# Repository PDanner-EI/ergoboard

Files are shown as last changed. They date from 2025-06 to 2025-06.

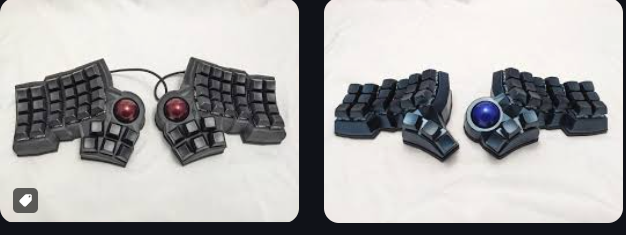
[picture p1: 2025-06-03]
obsidian/Keyboards/_images/kb_cosmos.png

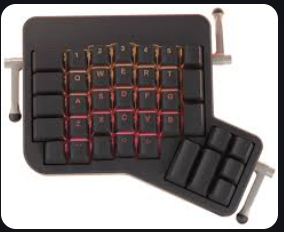
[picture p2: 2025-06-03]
obsidian/Keyboards/_images/kb_zsa_ergodox_ez.png

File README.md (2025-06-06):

# ergoboard
Repo to document all my progress and files on the journey of finding the most comfortable and efficient keyboard.

## Directories:
- See [3d_files](https://github.com/PDanner-EI/ergoboard/tree/main/3d_files) for all used 3d-files
- See [kle](https://github.com/PDanner-EI/ergoboard/tree/main/kle) for the visual layout .json of the keyboard, using Keyboard Layout Manager
- See [obsidian](https://github.com/PDanner-EI/ergoboard/tree/main/obsidian) for all documentations
- See [qmk_firmware](https://github.com/PDanner-EI/ergoboard/tree/main/qmk_firmware/cosmotyl) for the current firmware copied out of the QMK keyboard directory

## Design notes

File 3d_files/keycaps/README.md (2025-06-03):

Source: https://www.printables.com/model/865075-des-keycaps-for-keyboard-cherry-mx-version

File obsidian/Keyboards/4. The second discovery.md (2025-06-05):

# Cosmos keyboards
![[kb_cosmos.png]]
[Online tool](https://ryanis.cool/cosmos/beta)
+++fully customizable everything
+++solves all problems
++open source

ergonomic bonus:
+++fully ergonomic

bonus:
+encoders/trackballs/displays/joysticks
+wide range of controllers

---
[[5. The Cosmos keyboard V1|Next > The Cosmos keyboard V1]]

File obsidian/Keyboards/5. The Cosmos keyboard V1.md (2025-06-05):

Example:![[kb_cosmos_model.png]]

# Custom model V1
![[kb_cosmos_model_V1.png]]
[V1](https://ryanis.cool/cosmos/beta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)
+physical layout fully adjusted to my hands and fingers
+minimal layout 3x6 + 3 thumbs
+added trackball for faster scrolling and clicking
+added encoder (current application in testing)
+++solves all problems

ergonomic bonus:
+split
+angled keys
+thumb keys + angled

# Assembly guides
==!!!Definitely use thin magnet wire/Kupferlackdraht!!!==
https://ryanis.cool/cosmos/docs/qmk-rp2040/
https://ryanis.cool/cosmos/plum-twist/wiring

# Firmware
[QMK](https://docs.qmk.fm)

# Components
## Socket PCBs
* [Plum twist](https://github.com/rianadon/Cosmos-Keyboard-PCBs/tree/main/plum-twist)
	Individual small PCBs that rotate into place
	--super annoying and tedious to solder and wire
	++switch layout doesn't matter; can shape to any curvature
	+able to swap out the entire electronics without disassembly

## Keycaps
- 42+: 1u DES Keycaps
	- [x] print [DES keycaps(printables)(~0€)](https://www.printables.com/model/865075-des-keycaps-for-keyboard-cherry-mx-version)

## Switches
- 42+: MX-Compatible Switches
	- [x] test [Cherry MX experience box(amazon)(9,99€)](https://www.amazon.de/CHERRY-Tastatur-Schalter-Gaming-Keyboard-Ausprobieren-Kennenlernen/dp/B0CC2WZLQ3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)
	- [x] or [Cherry MX experience box(shop.cherry)(9,99€)](https://shop.cherry.de/de-de/mx-experience-box.html)
	- [x] [cherry silent red(amazon)(34,99)](https://www.amazon.de/dp/B09ZTGPPN6)
	- [x] [Gazzew Boba U4(splitkb)(33,58)](https://splitkb.com/products/gazzew-boba-u4-silent-tactile-switch?variant=43579262566659)

## Trackball
- 3: 3 x 6 x 2.5mm Bearings {option 1} (HARD TO TURN)
	- [ ] [4 Stueck MR63ZZ(ebay)(6,10€)](https://www.ebay.de/itm/376084342403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)
- 3: 3 x 8mm Dowel Pins {option 1} (HARD TO TURN)
	- [ ] [5 Zylinderstifte 3x8mm(ebay)(4,10)](https://www.ebay.de/itm/312197203836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)
- 3: BTU 7.5mm {option 2} (NOISY!!!)
	- [x] [Ball Transfer Unit 7.5 QB311(aliexpress)(2,85)](https://www.aliexpress.us/item/1005005411108700.html?gatewayAdapt=4itemAdapt)
- 3: Ball Bearings {option 3} (SILENT)
	- [x] salvaged from old drawer slide
- 1: PMW3360 or PMW3389 Sensor
	- [x] [PMW3389DM-T3QU(aliexpress)(8,09)](https://de.aliexpress.com/item/1005007468783392.html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)
- PMW3389 breakout [PCBs](https://github.com/Zorahmella/Ogen)
	- [x] Self-Ordered via JLCPCB
- 1: 34mm Trackball
	- [x] [Perixx Peripro-303 Ersatztrackball(amazon)(12,03)](https://www.amazon.de/Perixx-PERIPRO-303GB-Trackball-Ersatzball-Kensington/dp/B07BDF725X?th=1)
	- [ ] [Perixx Peripro-303 Ersatztrackball(perixx)(11,99)](https://de.perixx.com/products/peripro-303_glossy?variant=48187580449033)

## Encoders
- 2: EC11
	- [x] [5 EC11(aliexpress)(1,39)](https://de.aliexpress.com/item/1005005983134515.html)
- 67+: 1N148 Diodes
	- [x] [1N4180(reichelt)(1,90)](https://www.reichelt.de/de/de/shop/produkt/schalt-diode_100_v_150_ma_do-35-1730)

## Mounting
- 18: M3 x 6mm Flat Head Screws
	- [ ] baumarkt?
- 2: M3 x 8mm Flat Head Screws
	- [ ] baumarkt?
- 20: M3 Screw Inserts
	- [x] [100 M3x4 Gewindeeinsatz(reichelt)(8,99)](https://www.reichelt.de/de/de/shop/produkt/3d_druck_gewindeeinsaetze_m3x4_short_100_stueck-332214)

## Electrical
- 2: RP2040-Zero
	- [x] [Hailege RP2040-Zero(amazon)(10,99)](https://www.amazon.de/gp/product/B0CJY3CDVY/ref=sw_img_1?smid=A1A7E5ILEFA1R3&psc=1)
- 2: PJ-320A TRRS Connectors
	- [x] [10 PJ-320A(aliexpress)(1,29)](https://de.aliexpress.com/item/1005003111662179.html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)
- 1: TRRS Cable
	- [x] [90degree TRRS(aliexpress)(5,59)](https://de.aliexpress.com/item/1005003415667083.html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"order"%3A"379"%2C"eval"%3A"1"%7D&pdp_npi=4%40dis%21EUR%214.08%210.99%21%21%214.41%211.07%21%402103846917439709888006490ea134%2112000025692890634%21sea%21DE%214712248397%21ACX&curPageLogUid=T2C27mSR1sqV&utparam-url=scene%3Asearch%7Cquery_from%3A)
- 1: Spool Wire Wrap or Magnet Wire
	- [x] [100g Kupferlackdraht 0,28(reichelt)(7,10)](https://www.reichelt.de/de/de/shop/produkt/100g_kupferlackdraht_auf_spule_0_28mm-57179)

## Others
- Rubber or Silicone Feet
	- [ ] baumarkt?

---
[[6. The training|Next > The training]]

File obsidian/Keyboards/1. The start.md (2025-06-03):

# The idea

- [ ] Finally learn to properly touch type instead of hunt and peck or hybrid. [wikipedia.org](https://en.wikipedia.org/wiki/Typing)

-> Much faster typing since I no longer have to look between screen and keyboard
-> Faster programming and more focus on the actual function of the code instead of the correct formatting
-> Faster navigation between windows because I can now use the shortcuts efficiently
-> Shift my overall focus away from the keyboard and towards what I'm actually trying to do

# The problem

1. I learned touch typing back in school, but never actually used it after
2. I'm already used to my hybrid system with about 4-5 fingers (Probably a consequence of 3. and 4.)
3. Moving my pinky finger to 'shift' or 'ctrl' requires me to make awkward reaches and pulls my fingers from their home row.
4. Too many keys require me to move away from the home row, wasting time and requiring me to look at my keyboard anyway.
5. Touch typing for programming feels too unnatural and awkward, because I constantly have to reach for all the brackets and re-home
6. Numpad useful but inefficient for programming. Also too many back and forth re-homing
7. Some key/shifted key combinations on qwerty/qwertz just don't make sense to me. Why `"` not on `'`?    `!`/`?`   `&`/`|`   `/`/`\`

# The solution

1. Relearn
2. Unlearn / Try to avoid
3. Different key layout or different physical keyswitch layout
4. Less overall keys
5. Different key layout / layers
6. Different key layout / layers
7. Custom key layout

---
[[2. The first discovery|Next > The first discovery]]

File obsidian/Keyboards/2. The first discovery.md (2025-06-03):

# Ergonomic keyboards

- split
	-> more natural shoulder and wrist rotation, because the keyboard halfs can be placed further apart and individually with additional space in between.
	
- angled rows and columns
	-> keys easier and more comfortably reachable by fingers
	
- added thumbkeys
	-> more functionality for a finger that is underused

---
[[3. The search|Next > The search]]

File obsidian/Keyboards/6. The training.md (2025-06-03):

# Training tools
https://www.keybr.com
- Free to use
- No signup required but saves your training progress across devices if you do
- Perfect to start learning completely from scratch or simply improving your WPM.
- Heavily configurable
- Cool, methodical concept: Start with 6 initially unlocked characters and bring your WPM up to a certain threshold, then unlock the next character and repeat.

https://monkeytype.com
- Free to use
- No signup required but saves your training progress across devices if you do
- Perfect to improve your WPM for specific tasks.
- Heavily configurable
- Practical concept: Select which language or **programming language** you want to improve and get random snippets to type

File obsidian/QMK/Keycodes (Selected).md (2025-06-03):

==------I excluded the keycodes I definitely don't (want) to use / linux / mac------==
# Keycodes Overview[](https://docs.qmk.fm/keycodes#keycodes-overview)

When defining a [keymap](https://docs.qmk.fm/keymap) each key needs a valid key definition. This page documents the symbols that correspond to keycodes that are available to you in QMK.

This is a reference only. Each group of keys links to the page documenting their functionality in more detail.

## Basic Keycodes[](https://docs.qmk.fm/keycodes#basic-keycodes)

See also: [Basic Keycodes](https://docs.qmk.fm/keycodes_basic)

| Key | Aliases | Description | Windows |
| --- | --- | --- | --- |
| `KC_NO` | `XXXXXXX` | Ignore this key (NOOP) | _N/A_ |
| `KC_TRANSPARENT` | `KC_TRNS`, `_______` | Use the next lowest non-transparent key | _N/A_ |
| `KC_A` | | `a` and `A` | ✔ |
| `KC_B` | | `b` and `B` | ✔ |
| `KC_C` | | `c` and `C` | ✔ |
| `KC_D` | | `d` and `D` | ✔ |
| `KC_E` | | `e` and `E` | ✔ |
| `KC_F` | | `f` and `F` | ✔ |
| `KC_G` | | `g` and `G` | ✔ |
| `KC_H` | | `h` and `H` | ✔ |
| `KC_I` | | `i` and `I` | ✔ |
| `KC_J` | | `j` and `J` | ✔ |
| `KC_K` | | `k` and `K` | ✔ |
| `KC_L` | | `l` and `L` | ✔ |
| `KC_M` | | `m` and `M` | ✔ |
| `KC_N` | | `n` and `N` | ✔ |
| `KC_O` | | `o` and `O` | ✔ |
| `KC_P` | | `p` and `P` | ✔ |
| `KC_Q` | | `q` and `Q` | ✔ |
| `KC_R` | | `r` and `R` | ✔ |
| `KC_S` | | `s` and `S` | ✔ |
| `KC_T` | | `t` and `T` | ✔ |
| `KC_U` | | `u` and `U` | ✔ |
| `KC_V` | | `v` and `V` | ✔ |
| `KC_W` | | `w` and `W` | ✔ |
| `KC_X` | | `x` and `X` | ✔ |
| `KC_Y` | | `y` and `Y` | ✔ |
| `KC_Z` | | `z` and `Z` | ✔ |
| `KC_1` | | `1` and `!` | ✔ |
| `KC_2` | | `2` and `@` | ✔ |
| `KC_3` | | `3` and `#` | ✔ |
| `KC_4` | | `4` and `$` | ✔ |
| `KC_5` | | `5` and `%` | ✔ |
| `KC_6` | | `6` and `^` | ✔ |
| `KC_7` | | `7` and `&` | ✔ |
| `KC_8` | | `8` and `*` | ✔ |
| `KC_9` | | `9` and `(` | ✔ |
| `KC_0` | | `0` and `)` | ✔ |
| `KC_ENTER` | `KC_ENT` | Return (Enter) | ✔ |
| `KC_ESCAPE` | `KC_ESC` | Escape | ✔ |
| `KC_BACKSPACE` | `KC_BSPC` | Delete (Backspace) | ✔ |
| `KC_TAB` | | Tab | ✔ |
| `KC_SPACE` | `KC_SPC` | Spacebar | ✔ |
| `KC_MINUS` | `KC_MINS` | `-` and `_` | ✔ |
| `KC_EQUAL` | `KC_EQL` | `=` and `+` | ✔ |
| `KC_LEFT_BRACKET` | `KC_LBRC` | `[` and `{` | ✔ |
| `KC_RIGHT_BRACKET` | `KC_RBRC` | `]` and `}` | ✔ |
| `KC_BACKSLASH` | `KC_BSLS` | `\` and `\|` | ✔ |
| `KC_NONUS_HASH` | `KC_NUHS` | Non-US `#` and `~` | ✔ |
| `KC_SEMICOLON` | `KC_SCLN` | `;` and `:` | ✔ |
| `KC_QUOTE` | `KC_QUOT` | `'` and `"` | ✔ |
| `KC_GRAVE` | `KC_GRV` | `` ` `` and `~` | ✔ |
| `KC_COMMA` | `KC_COMM` | `,` and `<` | ✔ |
| `KC_DOT` | | `.` and `>` | ✔ |
| `KC_SLASH` | `KC_SLSH` | `/` and `?` | ✔ |
| `KC_CAPS_LOCK` | `KC_CAPS` | Caps Lock | ✔ |
| `KC_F1` | | F1 | ✔ |
| `KC_F2` | | F2 | ✔ |
| `KC_F3` | | F3 | ✔ |
| `KC_F4` | | F4 | ✔ |
| `KC_F5` | | F5 | ✔ |
| `KC_F6` | | F6 | ✔ |
| `KC_F7` | | F7 | ✔ |
| `KC_F8` | | F8 | ✔ |
| `KC_F9` | | F9 | ✔ |
| `KC_F10` | | F10 | ✔ |
| `KC_F11` | | F11 | ✔ |
| `KC_F12` | | F12 | ✔ |
| `KC_PRINT_SCREEN` | `KC_PSCR` | Print Screen | ✔ |
| `KC_SCROLL_LOCK` | `KC_SCRL`, `KC_BRMD` | Scroll Lock, Brightness Down (macOS) | ✔ |
| `KC_PAUSE` | `KC_PAUS`, `KC_BRK`, `KC_BRMU`  | Pause, Brightness Up (macOS) | ✔ |
| `KC_INSERT` | `KC_INS` | Insert | ✔ |
| `KC_HOME` | | Home | ✔ |
| `KC_PAGE_UP` | `KC_PGUP` | Page Up | ✔ |
| `KC_DELETE` | `KC_DEL` | Forward Delete | ✔ |
| `KC_END` | | End | ✔ |
| `KC_PAGE_DOWN` | `KC_PGDN` | Page Down | ✔ |
| `KC_RIGHT` | `KC_RGHT` | Right Arrow | ✔ |
| `KC_LEFT` | | Left Arrow | ✔ |
| `KC_DOWN` | | Down Arrow | ✔ |
| `KC_UP` | | Up Arrow | ✔ |
| `KC_NUM_LOCK` | `KC_NUM` | Keypad Num Lock and Clear | ✔ |
| `KC_KP_SLASH` | `KC_PSLS` | Keypad `/` | ✔ |
| `KC_KP_ASTERISK` | `KC_PAST` | Keypad `*` | ✔ |
| `KC_KP_MINUS` | `KC_PMNS` | Keypad `-` | ✔ |
| `KC_KP_PLUS` | `KC_PPLS` | Keypad `+` | ✔ |
| `KC_KP_ENTER` | `KC_PENT` | Keypad Enter | ✔ |
| `KC_KP_1` | `KC_P1` | Keypad `1` and End | ✔ |
| `KC_KP_2` | `KC_P2` | Keypad `2` and Down Arrow | ✔ |
| `KC_KP_3` | `KC_P3` | Keypad `3` and Page Down | ✔ |
| `KC_KP_4` | `KC_P4` | Keypad `4` and Left Arrow | ✔ |
| `KC_KP_5` | `KC_P5` | Keypad `5` | ✔ |
| `KC_KP_6` | `KC_P6` | Keypad `6` and Right Arrow | ✔ |
| `KC_KP_7` | `KC_P7` | Keypad `7` and Home | ✔ |
| `KC_KP_8` | `KC_P8` | Keypad `8` and Up Arrow | ✔ |
| `KC_KP_9` | `KC_P9` | Keypad `9` and Page Up | ✔ |
| `KC_KP_0` | `KC_P0` | Keypad `0` and Insert | ✔ |
| `KC_KP_DOT` | `KC_PDOT` | Keypad `.` and Delete | ✔ |
| `KC_NONUS_BACKSLASH` | `KC_NUBS` | Non-US `\` and `\|` | ✔ |
| `KC_APPLICATION` | `KC_APP` | Application (Windows Context Menu Key)  | ✔ |
| `KC_KP_EQUAL` | `KC_PEQL` | Keypad `=` | ✔ |
| `KC_F13` | | F13 | ✔ |
| `KC_F14` | | F14 | ✔ |
| `KC_F15` | | F15 | ✔ |
| `KC_F16` | | F16 | ✔ |
| `KC_F17` | | F17 | ✔ |
| `KC_F18` | | F18 | ✔ |
| `KC_F19` | | F19 | ✔ |
| `KC_F20` | | F20 | ✔ |
| `KC_F21` | | F21 | ✔ |
| `KC_F22` | | F22 | ✔ |
| `KC_F23` | | F23 | ✔ |
| `KC_F24` | | F24 | ✔ |
| `KC_LOCKING_CAPS_LOCK` | `KC_LCAP` | Locking Caps Lock | ✔ |
| `KC_LOCKING_NUM_LOCK` | `KC_LNUM` | Locking Num Lock | ✔ |
| `KC_LOCKING_SCROLL_LOCK` | `KC_LSCR` | Locking Scroll Lock | ✔ |
| `KC_INTERNATIONAL_1` | `KC_INT1` | International 1 | ✔ |
| `KC_INTERNATIONAL_2` | `KC_INT2` | International 2 | ✔ |
| `KC_INTERNATIONAL_3` | `KC_INT3` | International 3 | ✔ |
| `KC_INTERNATIONAL_4` | `KC_INT4` | International 4 | ✔ |
| `KC_INTERNATIONAL_5` | `KC_INT5` | International 5 | ✔ |
| `KC_LEFT_CTRL` | `KC_LCTL` | Left Control | ✔ |
| `KC_LEFT_SHIFT` | `KC_LSFT` | Left Shift | ✔ |
| `KC_LEFT_ALT` | `KC_LALT`, `KC_LOPT` | Left Alt (Option) | ✔ |
| `KC_LEFT_GUI` | `KC_LGUI`, `KC_LCMD`, `KC_LWIN` | Left GUI (Windows/Command/Meta key) | ✔ |
| `KC_RIGHT_CTRL` | `KC_RCTL` | Right Control | ✔ |
| `KC_RIGHT_SHIFT` | `KC_RSFT` | Right Shift | ✔ |
| `KC_RIGHT_ALT` | `KC_RALT`, `KC_ROPT`, `KC_ALGR` | Right Alt (Option/AltGr) | ✔ |
| `KC_RIGHT_GUI` | `KC_RGUI`, `KC_RCMD`, `KC_RWIN` | Right GUI (Windows/Command/Meta key) | ✔ |
| `KC_SYSTEM_POWER` | `KC_PWR` | System Power Down | ✔ |
| `KC_SYSTEM_SLEEP` | `KC_SLEP` | System Sleep | ✔ |
| `KC_AUDIO_MUTE` | `KC_MUTE` | Mute | ✔ |
| `KC_AUDIO_VOL_UP` | `KC_VOLU` | Volume Up | ✔ |
| `KC_AUDIO_VOL_DOWN` | `KC_VOLD` | Volume Down | ✔ |
| `KC_MEDIA_NEXT_TRACK` | `KC_MNXT` | Next Track | ✔ |
| `KC_MEDIA_PREV_TRACK` | `KC_MPRV` | Previous Track | ✔ |
| `KC_MEDIA_STOP` | `KC_MSTP` | Stop Track | ✔ |
| `KC_MEDIA_PLAY_PAUSE` | `KC_MPLY` | Play/Pause Track | ✔ |
| `KC_MEDIA_SELECT` | `KC_MSEL` | Launch Media Player | ✔ |
| `KC_MAIL` | 656 | Launch Mail | ✔ |
| `KC_CALCULATOR` | `KC_CALC` | Launch Calculator | ✔ |
| `KC_MY_COMPUTER` | `KC_MYCM` | Launch My Computer | ✔ |
| `KC_WWW_SEARCH` | `KC_WSCH` | Browser Search | ✔ |
| `KC_WWW_HOME` | `KC_WHOM` | Browser Home | ✔ |
| `KC_WWW_BACK` | `KC_WBAK` | Browser Back | ✔ |
| `KC_WWW_FORWARD` | `KC_WFWD` | Browser Forward | ✔ |
| `KC_WWW_STOP` | `KC_WSTP` | Browser Stop | ✔ |
| `KC_WWW_REFRESH` | `KC_WREF` | Browser Refresh | ✔ |
| `KC_WWW_FAVORITES` | `KC_WFAV` | Browser Favorites | ✔ |
| `KC_MEDIA_FAST_FORWARD`  | `KC_MFFD` | Next Track | ✔ |
| `KC_MEDIA_REWIND` | `KC_MRWD` | Previous Track | ✔6 |
| `KC_BRIGHTNESS_UP` | `KC_BRIU` | Brightness Up | ✔ |
| `KC_BRIGHTNESS_DOWN` | `KC_BRID` | Brightness Down | ✔ |
| `KC_CONTROL_PANEL` | `KC_CPNL` | Open Control Panel | ✔ |
| `KC_ASSISTANT` | `KC_ASST` | Launch Context-Aware Assistant | ✔ |

6. WMP does not recognize the Rewind key, but both alter playback speed in VLC.

## Quantum Keycodes[](https://docs.qmk.fm/keycodes#quantum-keycodes)

See also: [Quantum Keycodes](https://docs.qmk.fm/quantum_keycodes#qmk-keycodes)

|Key|Aliases|Description|
|---|---|---|
|`QK_BOOTLOADER`|`QK_BOOT`|Put the keyboard into bootloader mode for flashing|
|`QK_DEBUG_TOGGLE`|`DB_TOGG`|Toggle debug mode|
|`QK_CLEAR_EEPROM`|`EE_CLR`|Reinitializes the keyboard's EEPROM (persistent memory)|
|`QK_MAKE`||Sends `qmk compile -kb (keyboard) -km (keymap)`, or `qmk flash` if shift is held. Puts keyboard into bootloader mode if shift & control are held|
|`QK_REBOOT`|`QK_RBT`|Resets the keyboard. Does not load the bootloader|

## Caps Word[](https://docs.qmk.fm/keycodes#caps-word)

See also: [Caps Word](https://docs.qmk.fm/features/caps_word)

|Key|Aliases|Description|
|---|---|---|
|`QK_CAPS_WORD_TOGGLE`|`CW_TOGG`|Toggles Caps Word|
Like Capslock but only for one word

## Key Lock[](https://docs.qmk.fm/keycodes#key-lock)

See also: [Key Lock](https://docs.qmk.fm/features/key_lock)

| Key | Description |
| --- | --- |
| `QK_LOCK` | Hold down the next key pressed, until the key is pressed again |

## Layer Switching[](https://docs.qmk.fm/keycodes#layer-switching)

See also: [Layer Switching](https://docs.qmk.fm/feature_layers#switching-and-toggling-layers)

| Key | Description |
| --- | --- |
| `DF(layer)` | Set the base (default) layer until the keyboard loses power |
| `PDF(layer)` | Set the base (default) layer in EEPROM |
| `MO(layer)` | Momentarily turn on `layer` when pressed (requires `KC_TRNS` on destination layer) |
| `OSL(layer)` | Momentarily activates `layer` until a key is pressed. See [One Shot Keys](https://docs.qmk.fm/one_shot_keys) for details. |
| `LM(layer, mod)` | Momentarily turn on `layer` (like MO) with `mod` active as well. Where `mod` is a mods_bit. Mods can be viewed [here](https://docs.qmk.fm/mod_tap). Example Implementation: `LM(LAYER_1, MOD_LALT)` |
| `LT(layer, kc)`  | Turn on `layer` when held, `kc` when tapped |
| `TG(layer)` | Toggle `layer` on or off |
| `TO(layer)` | Turns on `layer` and turns off all other layers, except the default layer |
| `TT(layer)` | Normally acts like MO unless it's tapped multiple times, which toggles `layer` on |

## Leader Key[](https://docs.qmk.fm/keycodes#leader-key)

See also: [Leader Key](https://docs.qmk.fm/features/leader_key)

|Key|Description|
|---|---|
|`QK_LEAD`|Begins a leader sequence|

## Mouse Keys[](https://docs.qmk.fm/keycodes#mouse-keys)

See also: [Mouse Keys](https://docs.qmk.fm/features/mouse_keys)

| Key | Aliases | Description |
| --- | --- | --- |
| `QK_MOUSE_CURSOR_UP` | `MS_UP` | Mouse cursor up |
| `QK_MOUSE_CURSOR_DOWN` | `MS_DOWN` | Mouse cursor down |
| `QK_MOUSE_CURSOR_LEFT` | `MS_LEFT` | Mouse cursor left |
| `QK_MOUSE_CURSOR_RIGHT` | `MS_RGHT` | Mouse cursor right |
| `QK_MOUSE_BUTTON_1` | `MS_BTN1` | Mouse button 1 |
| `QK_MOUSE_BUTTON_2` | `MS_BTN2` | Mouse button 2 |
| `QK_MOUSE_BUTTON_3` | `MS_BTN3` | Mouse button 3 |
| `QK_MOUSE_BUTTON_4` | `MS_BTN4` | Mouse button 4 |
| `QK_MOUSE_BUTTON_5` | `MS_BTN5` | Mouse button 5 |
| `QK_MOUSE_BUTTON_6` | `MS_BTN6` | Mouse button 6 |
| `QK_MOUSE_BUTTON_7` | `MS_BTN7` | Mouse button 7 |
| `QK_MOUSE_BUTTON_8` | `MS_BTN8` | Mouse button 8 |
| `QK_MOUSE_WHEEL_UP` | `MS_WHLU` | Mouse wheel up |
| `QK_MOUSE_WHEEL_DOWN` | `MS_WHLD` | Mouse wheel down |
| `QK_MOUSE_WHEEL_LEFT` | `MS_WHLL` | Mouse wheel left |
| `QK_MOUSE_WHEEL_RIGHT` | `MS_WHLR` | Mouse wheel right |
| `QK_MOUSE_ACCELERATION_0` | `MS_ACL0` | Set mouse acceleration to 0 |
| `QK_MOUSE_ACCELERATION_1` | `MS_ACL1` | Set mouse acceleration to 1 |
| `QK_MOUSE_ACCELERATION_2` | `MS_ACL2` | Set mouse acceleration to 2 |

## Modifiers[](https://docs.qmk.fm/keycodes#modifiers)

See also: [Modifier Keys](https://docs.qmk.fm/feature_advanced_keycodes#modifier-keys)

| Key | Aliases | Description |
| --- | --- | --- |
| `LCTL(kc)` | `C(kc)` | Hold Left Control and press `kc` |
| `LSFT(kc)` | `S(kc)` | Hold Left Shift and press `kc` |
| `LALT(kc)` | `A(kc)`, `LOPT(kc)` | Hold Left Alt and press `kc` |
| `LGUI(kc)` | `G(kc)`, `LCMD(kc)`, `LWIN(kc)` | Hold Left GUI and press `kc` |
| `RCTL(kc)` | | Hold Right Control and press `kc` |
| `RSFT(kc)` | | Hold Right Shift and press `kc` |
| `RALT(kc)` | `ROPT(kc)`, `ALGR(kc)` | Hold Right Alt (AltGr) and press `kc` |
| `RGUI(kc)` | `RCMD(kc)`, `RWIN(kc)` | Hold Right GUI and press `kc` |
| `LSG(kc)`  | `SGUI(kc)`, `SCMD(kc)`, `SWIN(kc)` | Hold Left Shift and Left GUI and press `kc` |
| `LAG(kc)`  | | Hold Left Alt and Left GUI and press `kc` |
| `RSG(kc)`  | | Hold Right Shift and Right GUI and press `kc` |
| `RAG(kc)`  | | Hold Right Alt and Right GUI and press `kc` |
| `LCA(kc)`  | | Hold Left Control and Alt and press `kc` |
| `LSA(kc)`  | | Hold Left Shift and Left Alt and press `kc` |
| `RSA(kc)`  | `SAGR(kc)` | Hold Right Shift and Right Alt (AltGr) and press `kc` |
| `RCS(kc)`  | | Hold Right Control and Right Shift and press `kc` |
| `LCAG(kc)` | | Hold Left Control, Alt and GUI and press `kc` |
| `MEH(kc)`  | | Hold Left Control, Shift and Alt and press `kc` |
| `HYPR(kc)` | | Hold Left Control, Shift, Alt and GUI and press `kc`  |
| `KC_MEH` | | Left Control, Shift and Alt |
| `KC_HYPR`  | | Left Control, Shift, Alt and GUI |

## Mod-Tap Keys[](https://docs.qmk.fm/keycodes#mod-tap-keys)

See also: [Mod-Tap](https://docs.qmk.fm/mod_tap)

| Key | Aliases | Description |
| --- | --- | --- |
| `MT(mod, kc)` | | `mod` when held, `kc` when tapped |
| `LCTL_T(kc)`  | `CTL_T(kc)` | Left Control when held, `kc` when tapped |
| `LSFT_T(kc)`  | `SFT_T(kc)` | Left Shift when held, `kc` when tapped |
| `LALT_T(kc)`  | `LOPT_T(kc)`, `ALT_T(kc)`, `OPT_T(kc)` | Left Alt when held, `kc` when tapped |
| `LGUI_T(kc)`  | `LCMD_T(kc)`, `LWIN_T(kc)`, `GUI_T(kc)`, `CMD_T(kc)`, `WIN_T(kc)` | Left GUI when held, `kc` when tapped |
| `RCTL_T(kc)`  | | Right Control when held, `kc` when tapped |
| `RSFT_T(kc)`  | | Right Shift when held, `kc` when tapped |
| `RALT_T(kc)`  | `ROPT_T(kc)`, `ALGR_T(kc)` | Right Alt (AltGr) when held, `kc` when tapped |
| `RGUI_T(kc)`  | `RCMD_T(kc)`, `RWIN_T(kc)` | Right GUI when held, `kc` when tapped |
| `LSG_T(kc)` | `SGUI_T(kc)`, `SCMD_T(kc)`, `SWIN_T(kc)` | Left Shift and GUI when held, `kc` when tapped |
| `LAG_T(kc)` | | Left Alt and GUI when held, `kc` when tapped |
| `RSG_T(kc)` | | Right Shift and GUI when held, `kc` when tapped |
| `RAG_T(kc)` | | Right Alt and GUI when held, `kc` when tapped |
| `LCA_T(kc)` | | Left Control and Alt when held, `kc` when tapped |
| `LSA_T(kc)` | | Left Shift and Left Alt when held, `kc` when tapped |
| `RSA_T(kc)` | `SAGR_T(kc)` | Right Shift and Right Alt (AltGr) when held, `kc` when tapped |
| `RCS_T(kc)` | | Right Control and Right Shift when held, `kc` when tapped |
| `LCAG_T(kc)`  | | Left Control, Alt and GUI when held, `kc` when tapped |
| `RCAG_T(kc)`  | | Right Control, Alt and GUI when held, `kc` when tapped |
| `C_S_T(kc)` | | Left Control and Shift when held, `kc` when tapped |
| `MEH_T(kc)` | | Left Control, Shift and Alt when held, `kc` when tapped |
| `HYPR_T(kc)`  | `ALL_T(kc)` | Left Control, Shift, Alt and GUI when held, `kc` when tapped - more info [here](https://brettterpstra.com/2012/12/08/a-useful-caps-lock-key/) |

## Tapping Term Keys[](https://docs.qmk.fm/keycodes#tapping-term-keys)

See also: [Dynamic Tapping Term](https://docs.qmk.fm/tap_hold#dynamic-tapping-term)

|Key|Aliases|Description|
|---|---|---|
|`QK_DYNAMIC_TAPPING_TERM_PRINT`|`DT_PRNT`|Types the current tapping term, in milliseconds|
|`QK_DYNAMIC_TAPPING_TERM_UP`|`DT_UP`|Increases the current tapping term by `DYNAMIC_TAPPING_TERM_INCREMENT`ms (5ms by default)|
|`QK_DYNAMIC_TAPPING_TERM_DOWN`|`DT_DOWN`|Decreases the current tapping term by `DYNAMIC_TAPPING_TERM_INCREMENT`ms (5ms by default)|

## US ANSI Shifted Symbols[](https://docs.qmk.fm/keycodes#us-ansi-shifted-symbols)

See also: [US ANSI Shifted Symbols](https://docs.qmk.fm/keycodes_us_ansi_shifted)

| Key | Aliases | Description |
| --- | --- | --- |
| `KC_TILDE` | `KC_TILD` | `~` |
| `KC_EXCLAIM` | `KC_EXLM` | `!` |
| `KC_AT` | | `@` |
| `KC_HASH` | | `#` |
| `KC_DOLLAR` | `KC_DLR` | `$` |
| `KC_PERCENT` | `KC_PERC` | `%` |
| `KC_CIRCUMFLEX` | `KC_CIRC` | `^` |
| `KC_AMPERSAND` | `KC_AMPR` | `&` |
| `KC_ASTERISK` | `KC_ASTR` | `*` |
| `KC_LEFT_PAREN` | `KC_LPRN` | `(` |
| `KC_RIGHT_PAREN` | `KC_RPRN` | `)` |
| `KC_UNDERSCORE` | `KC_UNDS` | `_` |
| `KC_PLUS` | | `+` |
| `KC_LEFT_CURLY_BRACE` | `KC_LCBR` | `{` |
| `KC_RIGHT_CURLY_BRACE` | `KC_RCBR` | `}` |
| `KC_PIPE` | | `\|` |
| `KC_COLON` | `KC_COLN` | `:` |
| `KC_DOUBLE_QUOTE` | `KC_DQUO`, `KC_DQT` | `"` |
| `KC_LEFT_ANGLE_BRACKET`  | `KC_LABK`, `KC_LT`  | `<` |
| `KC_RIGHT_ANGLE_BRACKET` | `KC_RABK`, `KC_GT`  | `>` |
| `KC_QUESTION` | `KC_QUES` | `?` |

## One Shot Keys[](https://docs.qmk.fm/keycodes#one-shot-keys)

See also: [One Shot Keys](https://docs.qmk.fm/one_shot_keys)

| Key | Aliases | Description |
| --- | --- | --- |
| `OSM(mod)` | | Hold `mod` for one keypress |
| `OSL(layer)` | | Switch to `layer` for one keypress |
| `QK_ONE_SHOT_TOGGLE` | `OS_TOGG` | Toggles One Shot keys status |
| `QK_ONE_SHOT_ON` | `OS_ON` | Turns One Shot keys on |
| `QK_ONE_SHOT_OFF` | `OS_OFF`  | Turns One Shot keys off |

## Repeat Key[](https://docs.qmk.fm/keycodes#repeat-key)

See also: [Repeat Key](https://docs.qmk.fm/features/repeat_key)

|Keycode|Aliases|Description|
|---|---|---|
|`QK_REPEAT_KEY`|`QK_REP`|Repeat the last pressed key|
|`QK_ALT_REPEAT_KEY`|`QK_AREP`|Perform alternate of the last key|

## Space Cadet[](https://docs.qmk.fm/keycodes#space-cadet)

See also: [Space Cadet](https://docs.qmk.fm/features/space_cadet)

| Key | Aliases | Description |
| --- | --- | --- |
| `QK_SPACE_CADET_LEFT_CTRL_PARENTHESIS_OPEN` | `SC_LCPO` | Left Control when held, `(` when tapped  |
| `QK_SPACE_CADET_RIGHT_CTRL_PARENTHESIS_CLOSE`  | `SC_RCPC` | Right Control when held, `)` when tapped |
| `QK_SPACE_CADET_LEFT_SHIFT_PARENTHESIS_OPEN` | `SC_LSPO` | Left Shift when held, `(` when tapped |
| `QK_SPACE_CADET_RIGHT_SHIFT_PARENTHESIS_CLOSE` | `SC_RSPC` | Right Shift when held, `)` when tapped |
| `QK_SPACE_CADET_LEFT_ALT_PARENTHESIS_OPEN` | `SC_LAPO` | Left Alt when held, `(` when tapped |
| `QK_SPACE_CADET_RIGHT_ALT_PARENTHESIS_CLOSE` | `SC_RAPC` | Right Alt when held, `)` when tapped |
| `QK_SPACE_CADET_RIGHT_SHIFT_ENTER` | `SC_SENT` | Right Shift when held, Enter when tapped |

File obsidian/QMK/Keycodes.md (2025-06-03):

# Keycodes Overview[](https://docs.qmk.fm/keycodes#keycodes-overview)

When defining a [keymap](https://docs.qmk.fm/keymap) each key needs a valid key definition. This page documents the symbols that correspond to keycodes that are available to you in QMK.

This is a reference only. Each group of keys links to the page documenting their functionality in more detail.

## Basic Keycodes[](https://docs.qmk.fm/keycodes#basic-keycodes)

See also: [Basic Keycodes](https://docs.qmk.fm/keycodes_basic)

| Key | Aliases | Description | Windows | macOS | Linux1 |
| --- | --- | --- | --- | ----- | --- |
| `KC_NO` | `XXXXXXX` | Ignore this key (NOOP) | _N/A_ | _N/A_ | _N/A_  |
| `KC_TRANSPARENT` | `KC_TRNS`, `_______` | Use the next lowest non-transparent key | _N/A_ | _N/A_ | _N/A_  |
| `KC_A` | | `a` and `A` | ✔ | ✔ | ✔ |
| `KC_B` | | `b` and `B` | ✔ | ✔ | ✔ |
| `KC_C` | | `c` and `C` | ✔ | ✔ | ✔ |
| `KC_D` | | `d` and `D` | ✔ | ✔ | ✔ |
| `KC_E` | | `e` and `E` | ✔ | ✔ | ✔ |
| `KC_F` | | `f` and `F` | ✔ | ✔ | ✔ |
| `KC_G` | | `g` and `G` | ✔ | ✔ | ✔ |
| `KC_H` | | `h` and `H` | ✔ | ✔ | ✔ |
| `KC_I` | | `i` and `I` | ✔ | ✔ | ✔ |
| `KC_J` | | `j` and `J` | ✔ | ✔ | ✔ |
| `KC_K` | | `k` and `K` | ✔ | ✔ | ✔ |
| `KC_L` | | `l` and `L` | ✔ | ✔ | ✔ |
| `KC_M` | | `m` and `M` | ✔ | ✔ | ✔ |
| `KC_N` | | `n` and `N` | ✔ | ✔ | ✔ |
| `KC_O` | | `o` and `O` | ✔ | ✔ | ✔ |
| `KC_P` | | `p` and `P` | ✔ | ✔ | ✔ |
| `KC_Q` | | `q` and `Q` | ✔ | ✔ | ✔ |
| `KC_R` | | `r` and `R` | ✔ | ✔ | ✔ |
| `KC_S` | | `s` and `S` | ✔ | ✔ | ✔ |
| `KC_T` | | `t` and `T` | ✔ | ✔ | ✔ |
| `KC_U` | | `u` and `U` | ✔ | ✔ | ✔ |
| `KC_V` | | `v` and `V` | ✔ | ✔ | ✔ |
| `KC_W` | | `w` and `W` | ✔ | ✔ | ✔ |
| `KC_X` | | `x` and `X` | ✔ | ✔ | ✔ |
| `KC_Y` | | `y` and `Y` | ✔ | ✔ | ✔ |
| `KC_Z` | | `z` and `Z` | ✔ | ✔ | ✔ |
| `KC_1` | | `1` and `!` | ✔ | ✔ | ✔ |
| `KC_2` | | `2` and `@` | ✔ | ✔ | ✔ |
| `KC_3` | | `3` and `#` | ✔ | ✔ | ✔ |
| `KC_4` | | `4` and `$` | ✔ | ✔ | ✔ |
| `KC_5` | | `5` and `%` | ✔ | ✔ | ✔ |
| `KC_6` | | `6` and `^` | ✔ | ✔ | ✔ |
| `KC_7` | | `7` and `&` | ✔ | ✔ | ✔ |
| `KC_8` | | `8` and `*` | ✔ | ✔ | ✔ |
| `KC_9` | | `9` and `(` | ✔ | ✔ | ✔ |
| `KC_0` | | `0` and `)` | ✔ | ✔ | ✔ |
| `KC_ENTER` | `KC_ENT` | Return (Enter) | ✔ | ✔ | ✔ |
| `KC_ESCAPE` | `KC_ESC` | Escape | ✔ | ✔ | ✔ |
| `KC_BACKSPACE` | `KC_BSPC` | Delete (Backspace) | ✔ | ✔ | ✔ |
| `KC_TAB` | | Tab | ✔ | ✔ | ✔ |
| `KC_SPACE` | `KC_SPC` | Spacebar | ✔ | ✔ | ✔ |
| `KC_MINUS` | `KC_MINS` | `-` and `_` | ✔ | ✔ | ✔ |
| `KC_EQUAL` | `KC_EQL` | `=` and `+` | ✔ | ✔ | ✔ |
| `KC_LEFT_BRACKET` | `KC_LBRC` | `[` and `{` | ✔ | ✔ | ✔ |
| `KC_RIGHT_BRACKET` | `KC_RBRC` | `]` and `}` | ✔ | ✔ | ✔ |
| `KC_BACKSLASH` | `KC_BSLS` | `\` and `\|` | ✔ | ✔ | ✔ |
| `KC_NONUS_HASH` | `KC_NUHS` | Non-US `#` and `~` | ✔ | ✔ | ✔ |
| `KC_SEMICOLON` | `KC_SCLN` | `;` and `:` | ✔ | ✔ | ✔ |
| `KC_QUOTE` | `KC_QUOT` | `'` and `"` | ✔ | ✔ | ✔ |
| `KC_GRAVE` | `KC_GRV` | `` ` `` and `~` | ✔ | ✔ | ✔ |
| `KC_COMMA` | `KC_COMM` | `,` and `<` | ✔ | ✔ | ✔ |
| `KC_DOT` | | `.` and `>` | ✔ | ✔ | ✔ |
| `KC_SLASH` | `KC_SLSH` | `/` and `?` | ✔ | ✔ | ✔ |
| `KC_CAPS_LOCK` | `KC_CAPS` | Caps Lock | ✔ | ✔ | ✔ |
| `KC_F1` | | F1 | ✔ | ✔ | ✔ |
| `KC_F2` | | F2 | ✔ | ✔ | ✔ |
| `KC_F3` | | F3 | ✔ | ✔ | ✔ |
| `KC_F4` | | F4 | ✔ | ✔ | ✔ |
| `KC_F5` | | F5 | ✔ | ✔ | ✔ |
| `KC_F6` | | F6 | ✔ | ✔ | ✔ |
| `KC_F7` | | F7 | ✔ | ✔ | ✔ |
| `KC_F8` | | F8 | ✔ | ✔ | ✔ |
| `KC_F9` | | F9 | ✔ | ✔ | ✔ |
| `KC_F10` | | F10 | ✔ | ✔ | ✔ |
| `KC_F11` | | F11 | ✔ | ✔ | ✔ |
| `KC_F12` | | F12 | ✔ | ✔ | ✔ |
| `KC_PRINT_SCREEN` | `KC_PSCR` | Print Screen | ✔ | ✔2 | ✔ |
| `KC_SCROLL_LOCK` | `KC_SCRL`, `KC_BRMD` | Scroll Lock, Brightness Down (macOS) | ✔ | ✔2 | ✔ |
| `KC_PAUSE` | `KC_PAUS`, `KC_BRK`, `KC_BRMU`  | Pause, Brightness Up (macOS) | ✔ | ✔2 | ✔ |
| `KC_INSERT` | `KC_INS` | Insert | ✔ | | ✔ |
| `KC_HOME` | | Home | ✔ | ✔ | ✔ |
| `KC_PAGE_UP` | `KC_PGUP` | Page Up | ✔ | ✔ | ✔ |
| `KC_DELETE` | `KC_DEL` | Forward Delete | ✔ | ✔ | ✔ |
| `KC_END` | | End | ✔ | ✔ | ✔ |
| `KC_PAGE_DOWN` | `KC_PGDN` | Page Down | ✔ | ✔ | ✔ |
| `KC_RIGHT` | `KC_RGHT` | Right Arrow | ✔ | ✔ | ✔ |
| `KC_LEFT` | | Left Arrow | ✔ | ✔ | ✔ |
| `KC_DOWN` | | Down Arrow | ✔ | ✔ | ✔ |
| `KC_UP` | | Up Arrow | ✔ | ✔ | ✔ |
| `KC_NUM_LOCK` | `KC_NUM` | Keypad Num Lock and Clear | ✔ | ✔ | ✔ |
| `KC_KP_SLASH` | `KC_PSLS` | Keypad `/` | ✔ | ✔ | ✔ |
| `KC_KP_ASTERISK` | `KC_PAST` | Keypad `*` | ✔ | ✔ | ✔ |
| `KC_KP_MINUS` | `KC_PMNS` | Keypad `-` | ✔ | ✔ | ✔ |
| `KC_KP_PLUS` | `KC_PPLS` | Keypad `+` | ✔ | ✔ | ✔ |
| `KC_KP_ENTER` | `KC_PENT` | Keypad Enter | ✔ | ✔ | ✔ |
| `KC_KP_1` | `KC_P1` | Keypad `1` and End | ✔ | ✔ | ✔ |
| `KC_KP_2` | `KC_P2` | Keypad `2` and Down Arrow | ✔ | ✔ | ✔ |
| `KC_KP_3` | `KC_P3` | Keypad `3` and Page Down | ✔ | ✔ | ✔ |
| `KC_KP_4` | `KC_P4` | Keypad `4` and Left Arrow | ✔ | ✔ | ✔ |
| `KC_KP_5` | `KC_P5` | Keypad `5` | ✔ | ✔ | ✔ |
| `KC_KP_6` | `KC_P6` | Keypad `6` and Right Arrow | ✔ | ✔ | ✔ |
| `KC_KP_7` | `KC_P7` | Keypad `7` and Home | ✔ | ✔ | ✔ |
| `KC_KP_8` | `KC_P8` | Keypad `8` and Up Arrow | ✔ | ✔ | ✔ |
| `KC_KP_9` | `KC_P9` | Keypad `9` and Page Up | ✔ | ✔ | ✔ |
| `KC_KP_0` | `KC_P0` | Keypad `0` and Insert | ✔ | ✔ | ✔ |
| `KC_KP_DOT` | `KC_PDOT` | Keypad `.` and Delete | ✔ | ✔ | ✔ |
| `KC_NONUS_BACKSLASH` | `KC_NUBS` | Non-US `\` and `\|` | ✔ | ✔ | ✔ |
| `KC_APPLICATION` | `KC_APP` | Application (Windows Context Menu Key)  | ✔ | | ✔ |
| `KC_KB_POWER` | | System Power | | ✔3 | ✔ |
| `KC_KP_EQUAL` | `KC_PEQL` | Keypad `=` | ✔ | ✔ | ✔ |
| `KC_F13` | | F13 | ✔ | ✔ | ✔ |
| `KC_F14` | | F14 | ✔ | ✔ | ✔ |
| `KC_F15` | | F15 | ✔ | ✔ | ✔ |
| `KC_F16` | | F16 | ✔ | ✔ | ✔ |
| `KC_F17` | | F17 | ✔ | ✔ | ✔ |
| `KC_F18` | | F18 | ✔ | ✔ | ✔ |
| `KC_F19` | | F19 | ✔ | ✔ | ✔ |
| `KC_F20` | | F20 | ✔ | | ✔ |
| `KC_F21` | | F21 | ✔ | | ✔ |
| `KC_F22` | | F22 | ✔ | | ✔ |
| `KC_F23` | | F23 | ✔ | | ✔ |
| `KC_F24` | | F24 | ✔ | | ✔ |
| `KC_EXECUTE` | `KC_EXEC` | Execute | | | ✔ |
| `KC_HELP` | | Help | | | ✔ |
| `KC_MENU` | | Menu | | | ✔ |
| `KC_SELECT` | `KC_SLCT` | Select | | | ✔ |
| `KC_STOP` | | Stop | | | ✔ |
| `KC_AGAIN` | `KC_AGIN` | Again | | | ✔ |
| `KC_UNDO` | | Undo | | | ✔ |
| `KC_CUT` | | Cut | | | ✔ |
| `KC_COPY` | | Copy | | | ✔ |
| `KC_PASTE` | `KC_PSTE` | Paste | | | ✔ |
| `KC_FIND` | | Find | | | ✔ |
| `KC_KB_MUTE` | | Mute | | ✔ | ✔ |
| `KC_KB_VOLUME_UP` | | Volume Up | | ✔ | ✔ |
| `KC_KB_VOLUME_DOWN` | | Volume Down | | ✔ | ✔ |
| `KC_LOCKING_CAPS_LOCK` | `KC_LCAP` | Locking Caps Lock | ✔ | ✔ | |
| `KC_LOCKING_NUM_LOCK` | `KC_LNUM` | Locking Num Lock | ✔ | ✔ | |
| `KC_LOCKING_SCROLL_LOCK` | `KC_LSCR` | Locking Scroll Lock | ✔ | ✔ | |
| `KC_KP_COMMA` | `KC_PCMM` | Keypad `,` | | | ✔ |
| `KC_KP_EQUAL_AS400` | | Keypad `=` on AS/400 keyboards | | | |
| `KC_INTERNATIONAL_1` | `KC_INT1` | International 1 | ✔ | | ✔ |
| `KC_INTERNATIONAL_2` | `KC_INT2` | International 2 | ✔ | | ✔ |
| `KC_INTERNATIONAL_3` | `KC_INT3` | International 3 | ✔ | | ✔ |
| `KC_INTERNATIONAL_4` | `KC_INT4` | International 4 | ✔ | | ✔ |
| `KC_INTERNATIONAL_5` | `KC_INT5` | International 5 | ✔ | | ✔ |
| `KC_INTERNATIONAL_6` | `KC_INT6` | International 6 | | | ✔ |
| `KC_INTERNATIONAL_7` | `KC_INT7` | International 7 | | | |
| `KC_INTERNATIONAL_8` | `KC_INT8` | International 8 | | | |
| `KC_INTERNATIONAL_9` | `KC_INT9` | International 9 | | | |
| `KC_LANGUAGE_1` | `KC_LNG1` | Language 1 | | | ✔ |
| `KC_LANGUAGE_2` | `KC_LNG2` | Language 2 | | | ✔ |
| `KC_LANGUAGE_3` | `KC_LNG3` | Language 3 | | | ✔ |
| `KC_LANGUAGE_4` | `KC_LNG4` | Language 4 | | | ✔ |
| `KC_LANGUAGE_5` | `KC_LNG5` | Language 5 | | | ✔ |
| `KC_LANGUAGE_6` | `KC_LNG6` | Language 6 | | | |
| `KC_LANGUAGE_7` | `KC_LNG7` | Language 7 | | | |
| `KC_LANGUAGE_8` | `KC_LNG8` | Language 8 | | | |
| `KC_LANGUAGE_9` | `KC_LNG9` | Language 9 | | | |
| `KC_ALTERNATE_ERASE` | `KC_ERAS` | Alternate Erase | | | |
| `KC_SYSTEM_REQUEST` | `KC_SYRQ` | SysReq/Attention | | | |
| `KC_CANCEL` | `KC_CNCL` | Cancel | | | |
| `KC_CLEAR` | `KC_CLR` | Clear | | | ✔ |
| `KC_PRIOR` | `KC_PRIR` | Prior | | | |
| `KC_RETURN` | `KC_RETN` | Return | | | |
| `KC_SEPARATOR` | `KC_SEPR` | Separator | | | |
| `KC_OUT` | | Out | | | |
| `KC_OPER` | | Oper | | | |
| `KC_CLEAR_AGAIN` | `KC_CLAG` | Clear/Again | | | |
| `KC_CRSEL` | `KC_CRSL` | CrSel/Props | | | |
| `KC_EXSEL` | `KC_EXSL` | ExSel | | | |
| `KC_LEFT_CTRL` | `KC_LCTL` | Left Control | ✔ | ✔ | ✔ |
| `KC_LEFT_SHIFT` | `KC_LSFT` | Left Shift | ✔ | ✔ | ✔ |
| `KC_LEFT_ALT` | `KC_LALT`, `KC_LOPT` | Left Alt (Option) | ✔ | ✔ | ✔ |
| `KC_LEFT_GUI` | `KC_LGUI`, `KC_LCMD`, `KC_LWIN` | Left GUI (Windows/Command/Meta key) | ✔ | ✔ | ✔ |
| `KC_RIGHT_CTRL` | `KC_RCTL` | Right Control | ✔ | ✔ | ✔ |
| `KC_RIGHT_SHIFT` | `KC_RSFT` | Right Shift | ✔ | ✔ | ✔ |
| `KC_RIGHT_ALT` | `KC_RALT`, `KC_ROPT`, `KC_ALGR` | Right Alt (Option/AltGr) | ✔ | ✔ | ✔ |
| `KC_RIGHT_GUI` | `KC_RGUI`, `KC_RCMD`, `KC_RWIN` | Right GUI (Windows/Command/Meta key) | ✔ | ✔ | ✔ |
| `KC_SYSTEM_POWER` | `KC_PWR` | System Power Down | ✔ | ✔3 | ✔ |
| `KC_SYSTEM_SLEEP` | `KC_SLEP` | System Sleep | ✔ | ✔3 | ✔ |
| `KC_SYSTEM_WAKE` | `KC_WAKE` | System Wake | | ✔3 | ✔ |
| `KC_AUDIO_MUTE` | `KC_MUTE` | Mute | ✔ | ✔ | ✔ |
| `KC_AUDIO_VOL_UP` | `KC_VOLU` | Volume Up | ✔ | ✔4 | ✔ |
| `KC_AUDIO_VOL_DOWN` | `KC_VOLD` | Volume Down | ✔ | ✔4 | ✔ |
| `KC_MEDIA_NEXT_TRACK` | `KC_MNXT` | Next Track | ✔ | ✔5 | ✔ |
| `KC_MEDIA_PREV_TRACK` | `KC_MPRV` | Previous Track | ✔ | ✔5 | ✔ |
| `KC_MEDIA_STOP` | `KC_MSTP` | Stop Track | ✔ | | ✔ |
| `KC_MEDIA_PLAY_PAUSE` | `KC_MPLY` | Play/Pause Track | ✔ | ✔ | ✔ |
| `KC_MEDIA_SELECT` | `KC_MSEL` | Launch Media Player | ✔ | | ✔ |
| `KC_MEDIA_EJECT` | `KC_EJCT` | Eject | | ✔ | ✔ |
| `KC_MAIL` | | Launch Mail | ✔ | | ✔ |
| `KC_CALCULATOR` | `KC_CALC` | Launch Calculator | ✔ | | ✔ |
| `KC_MY_COMPUTER` | `KC_MYCM` | Launch My Computer | ✔ | | ✔ |
| `KC_WWW_SEARCH` | `KC_WSCH` | Browser Search | ✔ | | ✔ |
| `KC_WWW_HOME` | `KC_WHOM` | Browser Home | ✔ | | ✔ |
| `KC_WWW_BACK` | `KC_WBAK` | Browser Back | ✔ | | ✔ |
| `KC_WWW_FORWARD` | `KC_WFWD` | Browser Forward | ✔ | | ✔ |
| `KC_WWW_STOP` | `KC_WSTP` | Browser Stop | ✔ | | ✔ |
| `KC_WWW_REFRESH` | `KC_WREF` | Browser Refresh | ✔ | | ✔ |
| `KC_WWW_FAVORITES` | `KC_WFAV` | Browser Favorites | ✔ | | ✔ |
| `KC_MEDIA_FAST_FORWARD`  | `KC_MFFD` | Next Track | ✔ | ✔5 | ✔ |
| `KC_MEDIA_REWIND` | `KC_MRWD` | Previous Track | ✔6 | ✔5 | ✔ |
| `KC_BRIGHTNESS_UP` | `KC_BRIU` | Brightness Up | ✔ | ✔ | ✔ |
| `KC_BRIGHTNESS_DOWN` | `KC_BRID` | Brightness Down | ✔ | ✔ | ✔ |
| `KC_CONTROL_PANEL` | `KC_CPNL` | Open Control Panel | ✔ | | |
| `KC_ASSISTANT` | `KC_ASST` | Launch Context-Aware Assistant | ✔ | | |
| `KC_MISSION_CONTROL` | `KC_MCTL` | Open Mission Control | | ✔ | |
| `KC_LAUNCHPAD` | `KC_LPAD` | Open Launchpad | | ✔ | |

1. The Linux kernel HID driver recognizes [nearly all keycodes](https://github.com/torvalds/linux/blob/master/drivers/hid/hid-input.c), but the default bindings depend on the DE/WM.  
2. Treated as F13-F15.  
3. Must be held for about three seconds, and will display a prompt instead.  
4. Holding Shift+Option allows for finer control of volume level.  
5. Skips the entire track in iTunes when tapped, seeks within the current track when held.  
6. WMP does not recognize the Rewind key, but both alter playback speed in VLC.

## Quantum Keycodes[](https://docs.qmk.fm/keycodes#quantum-keycodes)

See also: [Quantum Keycodes](https://docs.qmk.fm/quantum_keycodes#qmk-keycodes)

|Key|Aliases|Description|
|---|---|---|
|`QK_BOOTLOADER`|`QK_BOOT`|Put the keyboard into bootloader mode for flashing|
|`QK_DEBUG_TOGGLE`|`DB_TOGG`|Toggle debug mode|
|`QK_CLEAR_EEPROM`|`EE_CLR`|Reinitializes the keyboard's EEPROM (persistent memory)|
|`QK_MAKE`||Sends `qmk compile -kb (keyboard) -km (keymap)`, or `qmk flash` if shift is held. Puts keyboard into bootloader mode if shift & control are held|
|`QK_REBOOT`|`QK_RBT`|Resets the keyboard. Does not load the bootloader|

## Audio Keys[](https://docs.qmk.fm/keycodes#audio-keys)

See also: [Audio](https://docs.qmk.fm/features/audio)

|Key|Aliases|Description|
|---|---|---|
|`QK_AUDIO_ON`|`AU_ON`|Turns on Audio Feature|
|`QK_AUDIO_OFF`|`AU_OFF`|Turns off Audio Feature|
|`QK_AUDIO_TOGGLE`|`AU_TOGG`|Toggles Audio state|
|`QK_AUDIO_CLICKY_TOGGLE`|`CK_TOGG`|Toggles Audio clicky mode|
|`QK_AUDIO_CLICKY_ON`|`CK_ON`|Turns on Audio clicky mode|
|`QK_AUDIO_CLICKY_OFF`|`CK_OFF`|Turns on Audio clicky mode|
|`QK_AUDIO_CLICKY_UP`|`CK_UP`|Increases frequency of the clicks|
|`QK_AUDIO_CLICKY_DOWN`|`CK_DOWN`|Decreases frequency of the clicks|
|`QK_AUDIO_CLICKY_RESET`|`CK_RST`|Resets frequency to default|
|`QK_MUSIC_ON`|`MU_ON`|Turns on Music Mode|
|`QK_MUSIC_OFF`|`MU_OFF`|Turns off Music Mode|
|`QK_MUSIC_TOGGLE`|`MU_TOGG`|Toggles Music Mode|
|`QK_MUSIC_MODE_NEXT`|`MU_NEXT`|Cycles through the music modes|
|`QK_AUDIO_VOICE_NEXT`|`AU_NEXT`|Cycles through the audio voices|
|`QK_AUDIO_VOICE_PREVIOUS`|`AU_PREV`|Cycles through the audio voices in reverse|

## Auto Shift[](https://docs.qmk.fm/keycodes#auto-shift)

See also: [Auto Shift](https://docs.qmk.fm/features/auto_shift)

|Key|Aliases|Description|
|---|---|---|
|`QK_AUTO_SHIFT_DOWN`|`AS_DOWN`|Lower the Auto Shift timeout variable (down)|
|`QK_AUTO_SHIFT_UP`|`AS_UP`|Raise the Auto Shift timeout variable (up)|
|`QK_AUTO_SHIFT_REPORT`|`AS_RPT`|Report your current Auto Shift timeout value|
|`QK_AUTO_SHIFT_ON`|`AS_ON`|Turns on the Auto Shift Function|
|`QK_AUTO_SHIFT_OFF`|`AS_OFF`|Turns off the Auto Shift Function|
|`QK_AUTO_SHIFT_TOGGLE`|`AS_TOGG`|Toggles the state of the Auto Shift feature|

## Autocorrect[](https://docs.qmk.fm/keycodes#autocorrect)

See also: [Autocorrect](https://docs.qmk.fm/features/autocorrect)

|Key|Aliases|Description|
|---|---|---|
|`QK_AUTOCORRECT_ON`|`AC_ON`|Turns on the Autocorrect feature.|
|`QK_AUTOCORRECT_OFF`|`AC_OFF`|Turns off the Autocorrect feature.|
|`QK_AUTOCORRECT_TOGGLE`|`AC_TOGG`|Toggles the status of the Autocorrect feature.|

## Backlighting[](https://docs.qmk.fm/keycodes#backlighting)

See also: [Backlighting](https://docs.qmk.fm/features/backlight)

|Key|Aliases|Description|
|---|---|---|
|`QK_BACKLIGHT_TOGGLE`|`BL_TOGG`|Turn the backlight on or off|
|`QK_BACKLIGHT_STEP`|`BL_STEP`|Cycle through backlight levels|
|`QK_BACKLIGHT_ON`|`BL_ON`|Set the backlight to max brightness|
|`QK_BACKLIGHT_OFF`|`BL_OFF`|Turn the backlight off|
|`QK_BACKLIGHT_UP`|`BL_UP`|Increase the backlight level|
|`QK_BACKLIGHT_DOWN`|`BL_DOWN`|Decrease the backlight level|
|`QK_BACKLIGHT_TOGGLE_BREATHING`|`BL_BRTG`|Toggle backlight breathing|

## Wireless/Bluetooth[](https://docs.qmk.fm/keycodes#bluetooth)

See also: [Wireless](https://docs.qmk.fm/features/wireless)

|Key|Aliases|Description|
|---|---|---|
|`QK_OUTPUT_AUTO`|`OU_AUTO`|Automatically switch to USB when plugged in, otherwise use wireless|
|`QK_OUTPUT_NEXT`|`OU_NEXT`|Cycle forwards through USB, Bluetooth, and 2.4GHz (when available) **(not yet implemented)**|
|`QK_OUTPUT_PREV`|`OU_PREV`|Cycle backwards through USB, Bluetooth, and 2.4GHz (when available) **(not yet implemented)**|
|`QK_OUTPUT_NONE`|`OU_NONE`|Disable all output **(not yet implemented)**|
|`QK_OUTPUT_USB`|`OU_USB`|Output to USB only|
|`QK_OUTPUT_2P4GHZ`|`OU_2P4G`|Output to 2.4GHz only **(not yet implemented)**|
|`QK_OUTPUT_BLUETOOTH`|`OU_BT`|Output to Bluetooth only|
|`QK_BLUETOOTH_PROFILE_NEXT`|`BT_NEXT`|Move to the next Bluetooth profile **(not yet implemented)**|
|`QK_BLUETOOTH_PROFILE_PREV`|`BT_PREV`|Move to the previous Bluetooth profile **(not yet implemented)**|
|`QK_BLUETOOTH_UNPAIR`|`BT_UNPR`|Un-pair the current Bluetooth profile **(not yet implemented)**|
|`QK_BLUETOOTH_PROFILE1`|`BT_PRF1`|Swap to Bluetooth profile #1 **(not yet implemented)**|
|`QK_BLUETOOTH_PROFILE2`|`BT_PRF2`|Swap to Bluetooth profile #2 **(not yet implemented)**|
|`QK_BLUETOOTH_PROFILE3`|`BT_PRF3`|Swap to Bluetooth profile #3 **(not yet implemented)**|
|`QK_BLUETOOTH_PROFILE4`|`BT_PRF4`|Swap to Bluetooth profile #4 **(not yet implemented)**|
|`QK_BLUETOOTH_PROFILE5`|`BT_PRF5`|Swap to Bluetooth profile #5 **(not yet implemented)**|

## Caps Word[](https://docs.qmk.fm/keycodes#caps-word)

See also: [Caps Word](https://docs.qmk.fm/features/caps_word)

|Key|Aliases|Description|
|---|---|---|
|`QK_CAPS_WORD_TOGGLE`|`CW_TOGG`|Toggles Caps Word|

## Dynamic Macros[](https://docs.qmk.fm/keycodes#dynamic-macros)

See also: [Dynamic Macros](https://docs.qmk.fm/features/dynamic_macros)

|Key|Aliases|Description|
|---|---|---|
|`QK_DYNAMIC_MACRO_RECORD_START_1`|`DM_REC1`|Start recording Macro 1|
|`QK_DYNAMIC_MACRO_RECORD_START_2`|`DM_REC2`|Start recording Macro 2|
|`QK_DYNAMIC_MACRO_PLAY_1`|`DM_PLY1`|Replay Macro 1|
|`QK_DYNAMIC_MACRO_PLAY_2`|`DM_PLY2`|Replay Macro 2|
|`QK_DYNAMIC_MACRO_RECORD_STOP`|`DM_RSTP`|Finish the macro that is currently being recorded.|

## Grave Escape[](https://docs.qmk.fm/keycodes#grave-escape)

See also: [Grave Escape](https://docs.qmk.fm/features/grave_esc)

|Key|Aliases|Description|
|---|---|---|
|`QK_GRAVE_ESCAPE`|`QK_GESC`|Escape when pressed, `` ` `` when Shift or GUI are held|

## Joystick[](https://docs.qmk.fm/keycodes#joystick)

See also: [Joystick](https://docs.qmk.fm/features/joystick)

|Key|Aliases|Description|
|---|---|---|
|`QK_JOYSTICK_BUTTON_0`|`JS_0`|Button 0|
|`QK_JOYSTICK_BUTTON_1`|`JS_1`|Button 1|
|`QK_JOYSTICK_BUTTON_2`|`JS_2`|Button 2|
|`QK_JOYSTICK_BUTTON_3`|`JS_3`|Button 3|
|`QK_JOYSTICK_BUTTON_4`|`JS_4`|Button 4|
|`QK_JOYSTICK_BUTTON_5`|`JS_5`|Button 5|
|`QK_JOYSTICK_BUTTON_6`|`JS_6`|Button 6|
|`QK_JOYSTICK_BUTTON_7`|`JS_7`|Button 7|
|`QK_JOYSTICK_BUTTON_8`|`JS_8`|Button 8|
|`QK_JOYSTICK_BUTTON_9`|`JS_9`|Button 9|
|`QK_JOYSTICK_BUTTON_10`|`JS_10`|Button 10|
|`QK_JOYSTICK_BUTTON_11`|`JS_11`|Button 11|
|`QK_JOYSTICK_BUTTON_12`|`JS_12`|Button 12|
|`QK_JOYSTICK_BUTTON_13`|`JS_13`|Button 13|
|`QK_JOYSTICK_BUTTON_14`|`JS_14`|Button 14|
|`QK_JOYSTICK_BUTTON_15`|`JS_15`|Button 15|
|`QK_JOYSTICK_BUTTON_16`|`JS_16`|Button 16|
|`QK_JOYSTICK_BUTTON_17`|`JS_17`|Button 17|
|`QK_JOYSTICK_BUTTON_18`|`JS_18`|Button 18|
|`QK_JOYSTICK_BUTTON_19`|`JS_19`|Button 19|
|`QK_JOYSTICK_BUTTON_20`|`JS_20`|Button 20|
|`QK_JOYSTICK_BUTTON_21`|`JS_21`|Button 21|
|`QK_JOYSTICK_BUTTON_22`|`JS_22`|Button 22|
|`QK_JOYSTICK_BUTTON_23`|`JS_23`|Button 23|
|`QK_JOYSTICK_BUTTON_24`|`JS_24`|Button 24|
|`QK_JOYSTICK_BUTTON_25`|`JS_25`|Button 25|
|`QK_JOYSTICK_BUTTON_26`|`JS_26`|Button 26|
|`QK_JOYSTICK_BUTTON_27`|`JS_27`|Button 27|
|`QK_JOYSTICK_BUTTON_28`|`JS_28`|Button 28|
|`QK_JOYSTICK_BUTTON_29`|`JS_29`|Button 29|
|`QK_JOYSTICK_BUTTON_30`|`JS_30`|Button 30|
|`QK_JOYSTICK_BUTTON_31`|`JS_31`|Button 31|

## Key Lock[](https://docs.qmk.fm/keycodes#key-lock)

See also: [Key Lock](https://docs.qmk.fm/features/key_lock)

|Key|Description|
|---|---|
|`QK_LOCK`|Hold down the next key pressed, until the key is pressed again|

## Layer Lock[](https://docs.qmk.fm/keycodes#layer-lock)

See also: [Layer Lock](https://docs.qmk.fm/features/layer_lock)

|Key|Aliases|Description|
|---|---|---|
|`QK_LAYER_LOCK`|`QK_LLCK`|Locks or unlocks the highest layer|

## Layer Switching[](https://docs.qmk.fm/keycodes#layer-switching)

See also: [Layer Switching](https://docs.qmk.fm/feature_layers#switching-and-toggling-layers)

|Key|Description|
|---|---|
|`DF(layer)`|Set the base (default) layer until the keyboard loses power|
|`PDF(layer)`|Set the base (default) layer in EEPROM|
|`MO(layer)`|Momentarily turn on `layer` when pressed (requires `KC_TRNS` on destination layer)|
|`OSL(layer)`|Momentarily activates `layer` until a key is pressed. See [One Shot Keys](https://docs.qmk.fm/one_shot_keys) for details.|
|`LM(layer, mod)`|Momentarily turn on `layer` (like MO) with `mod` active as well. Where `mod` is a mods_bit. Mods can be viewed [here](https://docs.qmk.fm/mod_tap). Example Implementation: `LM(LAYER_1, MOD_LALT)`|
|`LT(layer, kc)`|Turn on `layer` when held, `kc` when tapped|
|`TG(layer)`|Toggle `layer` on or off|
|`TO(layer)`|Turns on `layer` and turns off all other layers, except the default layer|
|`TT(layer)`|Normally acts like MO unless it's tapped multiple times, which toggles `layer` on|

## Leader Key[](https://docs.qmk.fm/keycodes#leader-key)

See also: [Leader Key](https://docs.qmk.fm/features/leader_key)

|Key|Description|
|---|---|
|`QK_LEAD`|Begins a leader sequence|

## LED Matrix[](https://docs.qmk.fm/keycodes#led-matrix)

See also: [LED Matrix](https://docs.qmk.fm/features/led_matrix)

|Key|Aliases|Description|
|---|---|---|
|`QK_LED_MATRIX_ON`|`LM_ON`|Turn on LED Matrix|
|`QK_LED_MATRIX_OFF`|`LM_OFF`|Turn off LED Matrix|
|`QK_LED_MATRIX_TOGGLE`|`LM_TOGG`|Toggle LED Matrix on or off|
|`QK_LED_MATRIX_MODE_NEXT`|`LM_NEXT`|Cycle through animations|
|`QK_LED_MATRIX_MODE_PREVIOUS`|`LM_PREV`|Cycle through animations in reverse|
|`QK_LED_MATRIX_BRIGHTNESS_UP`|`LM_BRIU`|Increase the brightness level|
|`QK_LED_MATRIX_BRIGHTNESS_DOWN`|`LM_BRID`|Decrease the brightness level|
|`QK_LED_MATRIX_SPEED_UP`|`LM_SPDU`|Increase the animation speed|
|`QK_LED_MATRIX_SPEED_DOWN`|`LM_SPDD`|Decrease the animation speed|

## Magic Keycodes[](https://docs.qmk.fm/keycodes#magic-keycodes)

See also: [Magic Keycodes](https://docs.qmk.fm/keycodes_magic)

|Key|Aliases|Description|
|---|---|---|
|`QK_MAGIC_SWAP_CONTROL_CAPS_LOCK`|`CL_SWAP`|Swap Caps Lock and Left Control|
|`QK_MAGIC_UNSWAP_CONTROL_CAPS_LOCK`|`CL_NORM`|Unswap Caps Lock and Left Control|
|`QK_MAGIC_TOGGLE_CONTROL_CAPS_LOCK`|`CL_TOGG`|Toggle Caps Lock and Left Control swap|
|`QK_MAGIC_CAPS_LOCK_AS_CONTROL_ON`|`CL_CTRL`|Treat Caps Lock as Control|
|`QK_MAGIC_CAPS_LOCK_AS_CONTROL_OFF`|`CL_CAPS`|Stop treating Caps Lock as Control|
|`QK_MAGIC_SWAP_ESCAPE_CAPS_LOCK`|`EC_SWAP`|Swap Caps Lock and Escape|
|`QK_MAGIC_UNSWAP_ESCAPE_CAPS_LOCK`|`EC_NORM`|Unswap Caps Lock and Escape|
|`QK_MAGIC_TOGGLE_ESCAPE_CAPS_LOCK`|`EC_TOGG`|Toggle Caps Lock and Escape swap|
|`QK_MAGIC_SWAP_LCTL_LGUI`|`CG_LSWP`|Swap Left Control and GUI|
|`QK_MAGIC_UNSWAP_LCTL_LGUI`|`CG_LNRM`|Unswap Left Control and GUI|
|`QK_MAGIC_SWAP_RCTL_RGUI`|`CG_RSWP`|Swap Right Control and GUI|
|`QK_MAGIC_UNSWAP_RCTL_RGUI`|`CG_RNRM`|Unswap Right Control and GUI|
|`QK_MAGIC_SWAP_CTL_GUI`|`CG_SWAP`|Swap Control and GUI on both sides|
|`QK_MAGIC_UNSWAP_CTL_GUI`|`CG_NORM`|Unswap Control and GUI on both sides|
|`QK_MAGIC_TOGGLE_CTL_GUI`|`CG_TOGG`|Toggle Control and GUI swap on both sides|
|`QK_MAGIC_SWAP_LALT_LGUI`|`AG_LSWP`|Swap Left Alt and GUI|
|`QK_MAGIC_UNSWAP_LALT_LGUI`|`AG_LNRM`|Unswap Left Alt and GUI|
|`QK_MAGIC_SWAP_RALT_RGUI`|`AG_RSWP`|Swap Right Alt and GUI|
|`QK_MAGIC_UNSWAP_RALT_RGUI`|`AG_RNRM`|Unswap Right Alt and GUI|
|`QK_MAGIC_SWAP_ALT_GUI`|`AG_SWAP`|Swap Alt and GUI on both sides|
|`QK_MAGIC_UNSWAP_ALT_GUI`|`AG_NORM`|Unswap Alt and GUI on both sides|
|`QK_MAGIC_TOGGLE_ALT_GUI`|`AG_TOGG`|Toggle Alt and GUI swap on both sides|
|`QK_MAGIC_GUI_OFF`|`GU_OFF`|Disable the GUI keys|
|`QK_MAGIC_GUI_ON`|`GU_ON`|Enable the GUI keys|
|`QK_MAGIC_TOGGLE_GUI`|`GU_TOGG`|Toggles the status of the GUI keys|
|`QK_MAGIC_SWAP_GRAVE_ESC`|`GE_SWAP`|Swap `` ` `` and Escape|
|`QK_MAGIC_UNSWAP_GRAVE_ESC`|`GE_NORM`|Unswap `` ` `` and Escape|
|`QK_MAGIC_SWAP_BACKSLASH_BACKSPACE`|`BS_SWAP`|Swap `\` and Backspace|
|`QK_MAGIC_UNSWAP_BACKSLASH_BACKSPACE`|`BS_NORM`|Unswap `\` and Backspace|
|`QK_MAGIC_TOGGLE_BACKSLASH_BACKSPACE`|`BS_TOGG`|Toggle `\` and Backspace swap state|
|`QK_MAGIC_NKRO_ON`|`NK_ON`|Enable N-key rollover|
|`QK_MAGIC_NKRO_OFF`|`NK_OFF`|Disable N-key rollover|
|`QK_MAGIC_TOGGLE_NKRO`|`NK_TOGG`|Toggle N-key rollover|
|`QK_MAGIC_EE_HANDS_LEFT`|`EH_LEFT`|Set the master half of a split keyboard as the left hand (for `EE_HANDS`)|
|`QK_MAGIC_EE_HANDS_RIGHT`|`EH_RGHT`|Set the master half of a split keyboard as the right hand (for `EE_HANDS`)|

## MIDI[](https://docs.qmk.fm/keycodes#midi)

See also: [MIDI](https://docs.qmk.fm/features/midi)

|Key|Aliases|Description|
|---|---|---|
|`QK_MIDI_ON`|`MI_ON`|Turn MIDI on|
|`QK_MIDI_OFF`|`MI_OFF`|Turn MIDI off|
|`QK_MIDI_TOGGLE`|`MI_TOGG`|Toggle MIDI enabled|
|`QK_MIDI_NOTE_C_0`|`MI_C`|C octave 0|
|`QK_MIDI_NOTE_C_SHARP_0`|`MI_Cs`, `MI_Db`|C♯/D♭ octave 0|
|`QK_MIDI_NOTE_D_0`|`MI_D`|D octave 0|
|`QK_MIDI_NOTE_D_SHARP_0`|`MI_Ds`, `MI_Eb`|D♯/E♭ octave 0|
|`QK_MIDI_NOTE_E_0`|`MI_E`|E octave 0|
|`QK_MIDI_NOTE_F_0`|`MI_F`|F octave 0|
|`QK_MIDI_NOTE_F_SHARP_0`|`MI_Fs`, `MI_Gb`|F♯/G♭ octave 0|
|`QK_MIDI_NOTE_G_0`|`MI_G`|G octave 0|
|`QK_MIDI_NOTE_G_SHARP_0`|`MI_Gs`, `MI_Ab`|G♯/A♭ octave 0|
|`QK_MIDI_NOTE_A_0`|`MI_A`|A octave 0|
|`QK_MIDI_NOTE_A_SHARP_0`|`MI_As`, `MI_Bb`|A♯/B♭ octave 0|
|`QK_MIDI_NOTE_B_0`|`MI_B`|B octave 0|
|`QK_MIDI_NOTE_C_1`|`MI_C1`|C octave 1|
|`QK_MIDI_NOTE_C_SHARP_1`|`MI_Cs1`, `MI_Db1`|C♯/D♭ octave 1|
|`QK_MIDI_NOTE_D_1`|`MI_D1`|D octave 1|
|`QK_MIDI_NOTE_D_SHARP_1`|`MI_Ds1`, `MI_Eb1`|D♯/E♭ octave 1|
|`QK_MIDI_NOTE_E_1`|`MI_E1`|E octave 1|
|`QK_MIDI_NOTE_F_1`|`MI_F1`|F octave 1|
|`QK_MIDI_NOTE_F_SHARP_1`|`MI_Fs1`, `MI_Gb1`|F♯/G♭ octave 1|
|`QK_MIDI_NOTE_G_1`|`MI_G1`|G octave 1|
|`QK_MIDI_NOTE_G_SHARP_1`|`MI_Gs1`, `MI_Ab1`|G♯/A♭ octave 1|
|`QK_MIDI_NOTE_A_1`|`MI_A1`|A octave 1|
|`QK_MIDI_NOTE_A_SHARP_1`|`MI_As1`, `MI_Bb1`|A♯/B♭ octave 1|
|`QK_MIDI_NOTE_B_1`|`MI_B1`|B octave 1|
|`QK_MIDI_NOTE_C_2`|`MI_C2`|C octave 2|
|`QK_MIDI_NOTE_C_SHARP_2`|`MI_Cs2`, `MI_Db2`|C♯/D♭ octave 2|
|`QK_MIDI_NOTE_D_2`|`MI_D2`|D octave 2|
|`QK_MIDI_NOTE_D_SHARP_2`|`MI_Ds2`, `MI_Eb2`|D♯/E♭ octave 2|
|`QK_MIDI_NOTE_E_2`|`MI_E2`|E octave 2|
|`QK_MIDI_NOTE_F_2`|`MI_F2`|F octave 2|
|`QK_MIDI_NOTE_F_SHARP_2`|`MI_Fs2`, `MI_Gb2`|F♯/G♭ octave 2|
|`QK_MIDI_NOTE_G_2`|`MI_G2`|G octave 2|
|`QK_MIDI_NOTE_G_SHARP_2`|`MI_Gs2`, `MI_Ab2`|G♯/A♭ octave 2|
|`QK_MIDI_NOTE_A_2`|`MI_A2`|A octave 2|
|`QK_MIDI_NOTE_A_SHARP_2`|`MI_As2`, `MI_Bb2`|A♯/B♭ octave 2|
|`QK_MIDI_NOTE_B_2`|`MI_B2`|B octave 2|
|`QK_MIDI_NOTE_C_3`|`MI_C3`|C octave 3|
|`QK_MIDI_NOTE_C_SHARP_3`|`MI_Cs3`, `MI_Db3`|C♯/D♭ octave 3|
|`QK_MIDI_NOTE_D_3`|`MI_D3`|D octave 3|
|`QK_MIDI_NOTE_D_SHARP_3`|`MI_Ds3`, `MI_Eb3`|D♯/E♭ octave 3|
|`QK_MIDI_NOTE_E_3`|`MI_E3`|E octave 3|
|`QK_MIDI_NOTE_F_3`|`MI_F3`|F octave 3|
|`QK_MIDI_NOTE_F_SHARP_3`|`MI_Fs3`, `MI_Gb3`|F♯/G♭ octave 3|
|`QK_MIDI_NOTE_G_3`|`MI_G3`|G octave 3|
|`QK_MIDI_NOTE_G_SHARP_3`|`MI_Gs3`, `MI_Ab3`|G♯/A♭ octave 3|
|`QK_MIDI_NOTE_A_3`|`MI_A3`|A octave 3|
|`QK_MIDI_NOTE_A_SHARP_3`|`MI_As3`, `MI_Bb3`|A♯/B♭ octave 3|
|`QK_MIDI_NOTE_B_3`|`MI_B3`|B octave 3|
|`QK_MIDI_NOTE_C_4`|`MI_C4`|C octave 4|
|`QK_MIDI_NOTE_C_SHARP_4`|`MI_Cs4`, `MI_Db4`|C♯/D♭ octave 4|
|`QK_MIDI_NOTE_D_4`|`MI_D4`|D octave 4|
|`QK_MIDI_NOTE_D_SHARP_4`|`MI_Ds4`, `MI_Eb4`|D♯/E♭ octave 4|
|`QK_MIDI_NOTE_E_4`|`MI_E4`|E octave 4|
|`QK_MIDI_NOTE_F_4`|`MI_F4`|F octave 4|
|`QK_MIDI_NOTE_F_SHARP_4`|`MI_Fs4`, `MI_Gb4`|F♯/G♭ octave 4|
|`QK_MIDI_NOTE_G_4`|`MI_G4`|G octave 4|
|`QK_MIDI_NOTE_G_SHARP_4`|`MI_Gs4`, `MI_Ab4`|G♯/A♭ octave 4|
|`QK_MIDI_NOTE_A_4`|`MI_A4`|A octave 4|
|`QK_MIDI_NOTE_A_SHARP_4`|`MI_As4`, `MI_Bb4`|A♯/B♭ octave 4|
|`QK_MIDI_NOTE_B_4`|`MI_B4`|B octave 4|
|`QK_MIDI_NOTE_C_5`|`MI_C5`|C octave 5|
|`QK_MIDI_NOTE_C_SHARP_5`|`MI_Cs5`, `MI_Db5`|C♯/D♭ octave 5|
|`QK_MIDI_NOTE_D_5`|`MI_D5`|D octave 5|
|`QK_MIDI_NOTE_D_SHARP_5`|`MI_Ds5`, `MI_Eb5`|D♯/E♭ octave 5|
|`QK_MIDI_NOTE_E_5`|`MI_E5`|E octave 5|
|`QK_MIDI_NOTE_F_5`|`MI_F5`|F octave 5|
|`QK_MIDI_NOTE_F_SHARP_5`|`MI_Fs5`, `MI_Gb5`|F♯/G♭ octave 5|
|`QK_MIDI_NOTE_G_5`|`MI_G5`|G octave 5|
|`QK_MIDI_NOTE_G_SHARP_5`|`MI_Gs5`, `MI_Ab5`|G♯/A♭ octave 5|
|`QK_MIDI_NOTE_A_5`|`MI_A5`|A octave 5|
|`QK_MIDI_NOTE_A_SHARP_5`|`MI_As5`, `MI_Bb5`|A♯/B♭ octave 5|
|`QK_MIDI_NOTE_B_5`|`MI_B5`|B octave 5|
|`QK_MIDI_OCTAVE_N2`|`MI_OCN2`|Set octave to -2|
|`QK_MIDI_OCTAVE_N1`|`MI_OCN1`|Set octave to -1|
|`QK_MIDI_OCTAVE_0`|`MI_OC0`|Set octave to 0|
|`QK_MIDI_OCTAVE_1`|`MI_OC1`|Set octave to 1|
|`QK_MIDI_OCTAVE_2`|`MI_OC2`|Set octave to 2|
|`QK_MIDI_OCTAVE_3`|`MI_OC3`|Set octave to 3|
|`QK_MIDI_OCTAVE_4`|`MI_OC4`|Set octave to 4|
|`QK_MIDI_OCTAVE_5`|`MI_OC5`|Set octave to 5|
|`QK_MIDI_OCTAVE_6`|`MI_OC6`|Set octave to 6|
|`QK_MIDI_OCTAVE_7`|`MI_OC7`|Set octave to 7|
|`QK_MIDI_OCTAVE_DOWN`|`MI_OCTD`|Move down an octave|
|`QK_MIDI_OCTAVE_UP`|`MI_OCTU`|Move up an octave|
|`QK_MIDI_TRANSPOSE_N6`|`MI_TRN6`|Set transposition to -6 semitones|
|`QK_MIDI_TRANSPOSE_N5`|`MI_TRN5`|Set transposition to -5 semitones|
|`QK_MIDI_TRANSPOSE_N4`|`MI_TRN4`|Set transposition to -4 semitones|
|`QK_MIDI_TRANSPOSE_N3`|`MI_TRN3`|Set transposition to -3 semitones|
|`QK_MIDI_TRANSPOSE_N2`|`MI_TRN2`|Set transposition to -2 semitones|
|`QK_MIDI_TRANSPOSE_N1`|`MI_TRN1`|Set transposition to -1 semitone|
|`QK_MIDI_TRANSPOSE_0`|`MI_TR0`|No transposition|
|`QK_MIDI_TRANSPOSE_1`|`MI_TR1`|Set transposition to +1 semitone|
|`QK_MIDI_TRANSPOSE_2`|`MI_TR2`|Set transposition to +2 semitones|
|`QK_MIDI_TRANSPOSE_3`|`MI_TR3`|Set transposition to +3 semitones|
|`QK_MIDI_TRANSPOSE_4`|`MI_TR4`|Set transposition to +4 semitones|
|`QK_MIDI_TRANSPOSE_5`|`MI_TR5`|Set transposition to +5 semitones|
|`QK_MIDI_TRANSPOSE_6`|`MI_TR6`|Set transposition to +6 semitones|
|`QK_MIDI_TRANSPOSE_DOWN`|`MI_TRSD`|Decrease transposition|
|`QK_MIDI_TRANSPOSE_UP`|`MI_TRSU`|Increase transposition|
|`QK_MIDI_VELOCITY_0`|`MI_VL0`|Set velocity to 0|
|`QK_MIDI_VELOCITY_1`|`MI_VL1`|Set velocity to 12|
|`QK_MIDI_VELOCITY_2`|`MI_VL2`|Set velocity to 25|
|`QK_MIDI_VELOCITY_3`|`MI_VL3`|Set velocity to 38|
|`QK_MIDI_VELOCITY_4`|`MI_VL4`|Set velocity to 51|
|`QK_MIDI_VELOCITY_5`|`MI_VL5`|Set velocity to 64|
|`QK_MIDI_VELOCITY_6`|`MI_VL6`|Set velocity to 76|
|`QK_MIDI_VELOCITY_7`|`MI_VL7`|Set velocity to 89|
|`QK_MIDI_VELOCITY_8`|`MI_VL8`|Set velocity to 102|
|`QK_MIDI_VELOCITY_9`|`MI_VL9`|Set velocity to 114|
|`QK_MIDI_VELOCITY_10`|`MI_VL10`|Set velocity to 127|
|`QK_MIDI_VELOCITY_DOWN`|`MI_VELD`|Decrease velocity|
|`QK_MIDI_VELOCITY_UP`|`MI_VELU`|Increase velocity|
|`QK_MIDI_CHANNEL_1`|`MI_CH1`|Set channel to 1|
|`QK_MIDI_CHANNEL_2`|`MI_CH2`|Set channel to 2|
|`QK_MIDI_CHANNEL_3`|`MI_CH3`|Set channel to 3|
|`QK_MIDI_CHANNEL_4`|`MI_CH4`|Set channel to 4|
|`QK_MIDI_CHANNEL_5`|`MI_CH5`|Set channel to 5|
|`QK_MIDI_CHANNEL_6`|`MI_CH6`|Set channel to 6|
|`QK_MIDI_CHANNEL_7`|`MI_CH7`|Set channel to 7|
|`QK_MIDI_CHANNEL_8`|`MI_CH8`|Set channel to 8|
|`QK_MIDI_CHANNEL_9`|`MI_CH9`|Set channel to 9|
|`QK_MIDI_CHANNEL_10`|`MI_CH10`|Set channel to 10|
|`QK_MIDI_CHANNEL_11`|`MI_CH11`|Set channel to 11|
|`QK_MIDI_CHANNEL_12`|`MI_CH12`|Set channel to 12|
|`QK_MIDI_CHANNEL_13`|`MI_CH13`|Set channel to 13|
|`QK_MIDI_CHANNEL_14`|`MI_CH14`|Set channel to 14|
|`QK_MIDI_CHANNEL_15`|`MI_CH15`|Set channel to 15|
|`QK_MIDI_CHANNEL_16`|`MI_CH16`|Set channel to 16|
|`QK_MIDI_CHANNEL_DOWN`|`MI_CHND`|Decrease channel|
|`QK_MIDI_CHANNEL_UP`|`MI_CHNU`|Increase channel|
|`QK_MIDI_ALL_NOTES_OFF`|`MI_AOFF`|Stop all notes|
|`QK_MIDI_SUSTAIN`|`MI_SUST`|Sustain|
|`QK_MIDI_PORTAMENTO`|`MI_PORT`|Portmento|
|`QK_MIDI_SOSTENUTO`|`MI_SOST`|Sostenuto|
|`QK_MIDI_SOFT`|`MI_SOFT`|Soft Pedal|
|`QK_MIDI_LEGATO`|`MI_LEG`|Legato|
|`QK_MIDI_MODULATION`|`MI_MOD`|Modulation|
|`QK_MIDI_MODULATION_SPEED_DOWN`|`MI_MODD`|Decrease modulation speed|
|`QK_MIDI_MODULATION_SPEED_UP`|`MI_MODU`|Increase modulation speed|
|`QK_MIDI_PITCH_BEND_DOWN`|`MI_BNDD`|Bend pitch down|
|`QK_MIDI_PITCH_BEND_UP`|`MI_BNDU`|Bend pitch up|

## Mouse Keys[](https://docs.qmk.fm/keycodes#mouse-keys)

See also: [Mouse Keys](https://docs.qmk.fm/features/mouse_keys)

|Key|Aliases|Description|
|---|---|---|
|`QK_MOUSE_CURSOR_UP`|`MS_UP`|Mouse cursor up|
|`QK_MOUSE_CURSOR_DOWN`|`MS_DOWN`|Mouse cursor down|
|`QK_MOUSE_CURSOR_LEFT`|`MS_LEFT`|Mouse cursor left|
|`QK_MOUSE_CURSOR_RIGHT`|`MS_RGHT`|Mouse cursor right|
|`QK_MOUSE_BUTTON_1`|`MS_BTN1`|Mouse button 1|
|`QK_MOUSE_BUTTON_2`|`MS_BTN2`|Mouse button 2|
|`QK_MOUSE_BUTTON_3`|`MS_BTN3`|Mouse button 3|
|`QK_MOUSE_BUTTON_4`|`MS_BTN4`|Mouse button 4|
|`QK_MOUSE_BUTTON_5`|`MS_BTN5`|Mouse button 5|
|`QK_MOUSE_BUTTON_6`|`MS_BTN6`|Mouse button 6|
|`QK_MOUSE_BUTTON_7`|`MS_BTN7`|Mouse button 7|
|`QK_MOUSE_BUTTON_8`|`MS_BTN8`|Mouse button 8|
|`QK_MOUSE_WHEEL_UP`|`MS_WHLU`|Mouse wheel up|
|`QK_MOUSE_WHEEL_DOWN`|`MS_WHLD`|Mouse wheel down|
|`QK_MOUSE_WHEEL_LEFT`|`MS_WHLL`|Mouse wheel left|
|`QK_MOUSE_WHEEL_RIGHT`|`MS_WHLR`|Mouse wheel right|
|`QK_MOUSE_ACCELERATION_0`|`MS_ACL0`|Set mouse acceleration to 0|
|`QK_MOUSE_ACCELERATION_1`|`MS_ACL1`|Set mouse acceleration to 1|
|`QK_MOUSE_ACCELERATION_2`|`MS_ACL2`|Set mouse acceleration to 2|

## Modifiers[](https://docs.qmk.fm/keycodes#modifiers)

See also: [Modifier Keys](https://docs.qmk.fm/feature_advanced_keycodes#modifier-keys)

|Key|Aliases|Description|
|---|---|---|
|`LCTL(kc)`|`C(kc)`|Hold Left Control and press `kc`|
|`LSFT(kc)`|`S(kc)`|Hold Left Shift and press `kc`|
|`LALT(kc)`|`A(kc)`, `LOPT(kc)`|Hold Left Alt and press `kc`|
|`LGUI(kc)`|`G(kc)`, `LCMD(kc)`, `LWIN(kc)`|Hold Left GUI and press `kc`|
|`RCTL(kc)`||Hold Right Control and press `kc`|
|`RSFT(kc)`||Hold Right Shift and press `kc`|
|`RALT(kc)`|`ROPT(kc)`, `ALGR(kc)`|Hold Right Alt (AltGr) and press `kc`|
|`RGUI(kc)`|`RCMD(kc)`, `RWIN(kc)`|Hold Right GUI and press `kc`|
|`LSG(kc)`|`SGUI(kc)`, `SCMD(kc)`, `SWIN(kc)`|Hold Left Shift and Left GUI and press `kc`|
|`LAG(kc)`||Hold Left Alt and Left GUI and press `kc`|
|`RSG(kc)`||Hold Right Shift and Right GUI and press `kc`|
|`RAG(kc)`||Hold Right Alt and Right GUI and press `kc`|
|`LCA(kc)`||Hold Left Control and Alt and press `kc`|
|`LSA(kc)`||Hold Left Shift and Left Alt and press `kc`|
|`RSA(kc)`|`SAGR(kc)`|Hold Right Shift and Right Alt (AltGr) and press `kc`|
|`RCS(kc)`||Hold Right Control and Right Shift and press `kc`|
|`LCAG(kc)`||Hold Left Control, Alt and GUI and press `kc`|
|`MEH(kc)`||Hold Left Control, Shift and Alt and press `kc`|
|`HYPR(kc)`||Hold Left Control, Shift, Alt and GUI and press `kc`|
|`KC_MEH`||Left Control, Shift and Alt|
|`KC_HYPR`||Left Control, Shift, Alt and GUI|

## Mod-Tap Keys[](https://docs.qmk.fm/keycodes#mod-tap-keys)

See also: [Mod-Tap](https://docs.qmk.fm/mod_tap)

|Key|Aliases|Description|
|---|---|---|
|`MT(mod, kc)`||`mod` when held, `kc` when tapped|
|`LCTL_T(kc)`|`CTL_T(kc)`|Left Control when held, `kc` when tapped|
|`LSFT_T(kc)`|`SFT_T(kc)`|Left Shift when held, `kc` when tapped|
|`LALT_T(kc)`|`LOPT_T(kc)`, `ALT_T(kc)`, `OPT_T(kc)`|Left Alt when held, `kc` when tapped|
|`LGUI_T(kc)`|`LCMD_T(kc)`, `LWIN_T(kc)`, `GUI_T(kc)`, `CMD_T(kc)`, `WIN_T(kc)`|Left GUI when held, `kc` when tapped|
|`RCTL_T(kc)`||Right Control when held, `kc` when tapped|
|`RSFT_T(kc)`||Right Shift when held, `kc` when tapped|
|`RALT_T(kc)`|`ROPT_T(kc)`, `ALGR_T(kc)`|Right Alt (AltGr) when held, `kc` when tapped|
|`RGUI_T(kc)`|`RCMD_T(kc)`, `RWIN_T(kc)`|Right GUI when held, `kc` when tapped|
|`LSG_T(kc)`|`SGUI_T(kc)`, `SCMD_T(kc)`, `SWIN_T(kc)`|Left Shift and GUI when held, `kc` when tapped|
|`LAG_T(kc)`||Left Alt and GUI when held, `kc` when tapped|
|`RSG_T(kc)`||Right Shift and GUI when held, `kc` when tapped|
|`RAG_T(kc)`||Right Alt and GUI when held, `kc` when tapped|
|`LCA_T(kc)`||Left Control and Alt when held, `kc` when tapped|
|`LSA_T(kc)`||Left Shift and Left Alt when held, `kc` when tapped|
|`RSA_T(kc)`|`SAGR_T(kc)`|Right Shift and Right Alt (AltGr) when held, `kc` when tapped|
|`RCS_T(kc)`||Right Control and Right Shift when held, `kc` when tapped|
|`LCAG_T(kc)`||Left Control, Alt and GUI when held, `kc` when tapped|
|`RCAG_T(kc)`||Right Control, Alt and GUI when held, `kc` when tapped|
|`C_S_T(kc)`||Left Control and Shift when held, `kc` when tapped|
|`MEH_T(kc)`||Left Control, Shift and Alt when held, `kc` when tapped|
|`HYPR_T(kc)`|`ALL_T(kc)`|Left Control, Shift, Alt and GUI when held, `kc` when tapped - more info [here](https://brettterpstra.com/2012/12/08/a-useful-caps-lock-key/)|

## Tapping Term Keys[](https://docs.qmk.fm/keycodes#tapping-term-keys)

See also: [Dynamic Tapping Term](https://docs.qmk.fm/tap_hold#dynamic-tapping-term)

|Key|Aliases|Description|
|---|---|---|
|`QK_DYNAMIC_TAPPING_TERM_PRINT`|`DT_PRNT`|Types the current tapping term, in milliseconds|
|`QK_DYNAMIC_TAPPING_TERM_UP`|`DT_UP`|Increases the current tapping term by `DYNAMIC_TAPPING_TERM_INCREMENT`ms (5ms by default)|
|`QK_DYNAMIC_TAPPING_TERM_DOWN`|`DT_DOWN`|Decreases the current tapping term by `DYNAMIC_TAPPING_TERM_INCREMENT`ms (5ms by default)|

## RGB Lighting[](https://docs.qmk.fm/keycodes#rgb-lighting)

See also: [RGB Lighting](https://docs.qmk.fm/features/rgblight)

|Key|Aliases|Description|
|---|---|---|
|`QK_UNDERGLOW_TOGGLE`|`UG_TOGG`|Toggle RGB lighting on or off|
|`QK_UNDERGLOW_MODE_NEXT`|`UG_NEXT`|Cycle through modes, reverse direction when Shift is held|
|`QK_UNDERGLOW_MODE_PREVIOUS`|`UG_PREV`|Cycle through modes in reverse, forward direction when Shift is held|
|`QK_UNDERGLOW_HUE_UP`|`UG_HUEU`|Increase hue, decrease hue when Shift is held|
|`QK_UNDERGLOW_HUE_DOWN`|`UG_HUED`|Decrease hue, increase hue when Shift is held|
|`QK_UNDERGLOW_SATURATION_UP`|`UG_SATU`|Increase saturation, decrease saturation when Shift is held|
|`QK_UNDERGLOW_SATURATION_DOWN`|`UG_SATD`|Decrease saturation, increase saturation when Shift is held|
|`QK_UNDERGLOW_VALUE_UP`|`UG_VALU`|Increase value (brightness), decrease value when Shift is held|
|`QK_UNDERGLOW_VALUE_DOWN`|`UG_VALD`|Decrease value (brightness), increase value when Shift is held|
|`QK_UNDERGLOW_SPEED_UP`|`UG_SPDU`|Increase effect speed (brightness), decrease speed when Shift is held|
|`QK_UNDERGLOW_SPEED_DOWN`|`UG_SPDD`|Decrease effect speed (brightness), increase speed when Shift is held|
|`RGB_MODE_PLAIN`|`RGB_M_P`|Static (no animation) mode (deprecated)|
|`RGB_MODE_BREATHE`|`RGB_M_B`|Breathing animation mode (deprecated)|
|`RGB_MODE_RAINBOW`|`RGB_M_R`|Rainbow animation mode (deprecated)|
|`RGB_MODE_SWIRL`|`RGB_M_SW`|Swirl animation mode (deprecated)|
|`RGB_MODE_SNAKE`|`RGB_M_SN`|Snake animation mode (deprecated)|
|`RGB_MODE_KNIGHT`|`RGB_M_K`|"Knight Rider" animation mode (deprecated)|
|`RGB_MODE_XMAS`|`RGB_M_X`|Christmas animation mode (deprecated)|
|`RGB_MODE_GRADIENT`|`RGB_M_G`|Static gradient animation mode (deprecated)|
|`RGB_MODE_RGBTEST`|`RGB_M_T`|Red, Green, Blue test animation mode (deprecated)|
|`RGB_MODE_TWINKLE`|`RGB_M_TW`|Twinkle animation mode (deprecated)|

## RGB Matrix[](https://docs.qmk.fm/keycodes#rgb-matrix)

See also: [RGB Matrix](https://docs.qmk.fm/features/rgb_matrix)

|Key|Aliases|Description|
|---|---|---|
|`QK_RGB_MATRIX_ON`|`RM_ON`|Turn on RGB Matrix|
|`QK_RGB_MATRIX_OFF`|`RM_OFF`|Turn off RGB Matrix|
|`QK_RGB_MATRIX_TOGGLE`|`RM_TOGG`|Toggle RGB Matrix on or off|
|`QK_RGB_MATRIX_MODE_NEXT`|`RM_NEXT`|Cycle through animations|
|`QK_RGB_MATRIX_MODE_PREVIOUS`|`RM_PREV`|Cycle through animations in reverse|
|`QK_RGB_MATRIX_HUE_UP`|`RM_HUEU`|Cycle through hue|
|`QK_RGB_MATRIX_HUE_DOWN`|`RM_HUED`|Cycle through hue in reverse|
|`QK_RGB_MATRIX_SATURATION_UP`|`RM_SATU`|Increase the saturation|
|`QK_RGB_MATRIX_SATURATION_DOWN`|`RM_SATD`|Decrease the saturation|
|`QK_RGB_MATRIX_VALUE_UP`|`RM_VALU`|Increase the brightness level|
|`QK_RGB_MATRIX_VALUE_DOWN`|`RM_VALD`|Decrease the brightness level|
|`QK_RGB_MATRIX_SPEED_UP`|`RM_SPDU`|Increase the animation speed|
|`QK_RGB_MATRIX_SPEED_DOWN`|`RM_SPDD`|Decrease the animation speed|

## US ANSI Shifted Symbols[](https://docs.qmk.fm/keycodes#us-ansi-shifted-symbols)

See also: [US ANSI Shifted Symbols](https://docs.qmk.fm/keycodes_us_ansi_shifted)

|Key|Aliases|Description|
|---|---|---|
|`KC_TILDE`|`KC_TILD`|`~`|
|`KC_EXCLAIM`|`KC_EXLM`|`!`|
|`KC_AT`||`@`|
|`KC_HASH`||`#`|
|`KC_DOLLAR`|`KC_DLR`|`$`|
|`KC_PERCENT`|`KC_PERC`|`%`|
|`KC_CIRCUMFLEX`|`KC_CIRC`|`^`|
|`KC_AMPERSAND`|`KC_AMPR`|`&`|
|`KC_ASTERISK`|`KC_ASTR`|`*`|
|`KC_LEFT_PAREN`|`KC_LPRN`|`(`|
|`KC_RIGHT_PAREN`|`KC_RPRN`|`)`|
|`KC_UNDERSCORE`|`KC_UNDS`|`_`|
|`KC_PLUS`||`+`|
|`KC_LEFT_CURLY_BRACE`|`KC_LCBR`|`{`|
|`KC_RIGHT_CURLY_BRACE`|`KC_RCBR`|`}`|
|`KC_PIPE`||`\|`|
|`KC_COLON`|`KC_COLN`|`:`|
|`KC_DOUBLE_QUOTE`|`KC_DQUO`, `KC_DQT`|`"`|
|`KC_LEFT_ANGLE_BRACKET`|`KC_LABK`, `KC_LT`|`<`|
|`KC_RIGHT_ANGLE_BRACKET`|`KC_RABK`, `KC_GT`|`>`|
|`KC_QUESTION`|`KC_QUES`|`?`|

## One Shot Keys[](https://docs.qmk.fm/keycodes#one-shot-keys)

See also: [One Shot Keys](https://docs.qmk.fm/one_shot_keys)

|Key|Aliases|Description|
|---|---|---|
|`OSM(mod)`||Hold `mod` for one keypress|
|`OSL(layer)`||Switch to `layer` for one keypress|
|`QK_ONE_SHOT_TOGGLE`|`OS_TOGG`|Toggles One Shot keys status|
|`QK_ONE_SHOT_ON`|`OS_ON`|Turns One Shot keys on|
|`QK_ONE_SHOT_OFF`|`OS_OFF`|Turns One Shot keys off|

## Programmable Button Support[](https://docs.qmk.fm/keycodes#programmable-button)

See also: [Programmable Button](https://docs.qmk.fm/features/programmable_button)

|Key|Aliases|Description|
|---|---|---|
|`QK_PROGRAMMABLE_BUTTON_1`|`PB_1`|Programmable button 1|
|`QK_PROGRAMMABLE_BUTTON_2`|`PB_2`|Programmable button 2|
|`QK_PROGRAMMABLE_BUTTON_3`|`PB_3`|Programmable button 3|
|`QK_PROGRAMMABLE_BUTTON_4`|`PB_4`|Programmable button 4|
|`QK_PROGRAMMABLE_BUTTON_5`|`PB_5`|Programmable button 5|
|`QK_PROGRAMMABLE_BUTTON_6`|`PB_6`|Programmable button 6|
|`QK_PROGRAMMABLE_BUTTON_7`|`PB_7`|Programmable button 7|
|`QK_PROGRAMMABLE_BUTTON_8`|`PB_8`|Programmable button 8|
|`QK_PROGRAMMABLE_BUTTON_9`|`PB_9`|Programmable button 9|
|`QK_PROGRAMMABLE_BUTTON_10`|`PB_10`|Programmable button 10|
|`QK_PROGRAMMABLE_BUTTON_11`|`PB_11`|Programmable button 11|
|`QK_PROGRAMMABLE_BUTTON_12`|`PB_12`|Programmable button 12|
|`QK_PROGRAMMABLE_BUTTON_13`|`PB_13`|Programmable button 13|
|`QK_PROGRAMMABLE_BUTTON_14`|`PB_14`|Programmable button 14|
|`QK_PROGRAMMABLE_BUTTON_15`|`PB_15`|Programmable button 15|
|`QK_PROGRAMMABLE_BUTTON_16`|`PB_16`|Programmable button 16|
|`QK_PROGRAMMABLE_BUTTON_17`|`PB_17`|Programmable button 17|
|`QK_PROGRAMMABLE_BUTTON_18`|`PB_18`|Programmable button 18|
|`QK_PROGRAMMABLE_BUTTON_19`|`PB_19`|Programmable button 19|
|`QK_PROGRAMMABLE_BUTTON_20`|`PB_20`|Programmable button 20|
|`QK_PROGRAMMABLE_BUTTON_21`|`PB_21`|Programmable button 21|
|`QK_PROGRAMMABLE_BUTTON_22`|`PB_22`|Programmable button 22|
|`QK_PROGRAMMABLE_BUTTON_23`|`PB_23`|Programmable button 23|
|`QK_PROGRAMMABLE_BUTTON_24`|`PB_24`|Programmable button 24|
|`QK_PROGRAMMABLE_BUTTON_25`|`PB_25`|Programmable button 25|
|`QK_PROGRAMMABLE_BUTTON_26`|`PB_26`|Programmable button 26|
|`QK_PROGRAMMABLE_BUTTON_27`|`PB_27`|Programmable button 27|
|`QK_PROGRAMMABLE_BUTTON_28`|`PB_28`|Programmable button 28|
|`QK_PROGRAMMABLE_BUTTON_29`|`PB_29`|Programmable button 29|
|`QK_PROGRAMMABLE_BUTTON_30`|`PB_30`|Programmable button 30|
|`QK_PROGRAMMABLE_BUTTON_31`|`PB_31`|Programmable button 31|
|`QK_PROGRAMMABLE_BUTTON_32`|`PB_32`|Programmable button 32|

## Repeat Key[](https://docs.qmk.fm/keycodes#repeat-key)

See also: [Repeat Key](https://docs.qmk.fm/features/repeat_key)

|Keycode|Aliases|Description|
|---|---|---|
|`QK_REPEAT_KEY`|`QK_REP`|Repeat the last pressed key|
|`QK_ALT_REPEAT_KEY`|`QK_AREP`|Perform alternate of the last key|

## Space Cadet[](https://docs.qmk.fm/keycodes#space-cadet)

See also: [Space Cadet](https://docs.qmk.fm/features/space_cadet)

|Key|Aliases|Description|
|---|---|---|
|`QK_SPACE_CADET_LEFT_CTRL_PARENTHESIS_OPEN`|`SC_LCPO`|Left Control when held, `(` when tapped|
|`QK_SPACE_CADET_RIGHT_CTRL_PARENTHESIS_CLOSE`|`SC_RCPC`|Right Control when held, `)` when tapped|
|`QK_SPACE_CADET_LEFT_SHIFT_PARENTHESIS_OPEN`|`SC_LSPO`|Left Shift when held, `(` when tapped|
|`QK_SPACE_CADET_RIGHT_SHIFT_PARENTHESIS_CLOSE`|`SC_RSPC`|Right Shift when held, `)` when tapped|
|`QK_SPACE_CADET_LEFT_ALT_PARENTHESIS_OPEN`|`SC_LAPO`|Left Alt when held, `(` when tapped|
|`QK_SPACE_CADET_RIGHT_ALT_PARENTHESIS_CLOSE`|`SC_RAPC`|Right Alt when held, `)` when tapped|
|`QK_SPACE_CADET_RIGHT_SHIFT_ENTER`|`SC_SENT`|Right Shift when held, Enter when tapped|

## Swap Hands[](https://docs.qmk.fm/keycodes#swap-hands)

See also: [Swap Hands](https://docs.qmk.fm/features/swap_hands)

|Key|Aliases|Description|
|---|---|---|
|`SH_T(kc)`||Momentary swap when held, `kc` when tapped|
|`QK_SWAP_HANDS_ON`|`SH_ON`|Turn on hand swap|
|`QK_SWAP_HANDS_OFF`|`SH_OFF`|Turn off hand swap|
|`QK_SWAP_HANDS_MOMENTARY_ON`|`SH_MON`|Turn on hand swap while held|
|`QK_SWAP_HANDS_MOMENTARY_OFF`|`SH_MOFF`|Turn off hand swap while held|
|`QK_SWAP_HANDS_TOGGLE`|`SH_TOGG`|Toggle hand swap|
|`QK_SWAP_HANDS_TAP_TOGGLE`|`SH_TT`|Momentary swap when held, toggle when tapped|
|`QK_SWAP_HANDS_ONE_SHOT`|`SH_OS`|Turn on hand swap while held or until next key press|

## Unicode Support[](https://docs.qmk.fm/keycodes#unicode-support)

See also: [Unicode Support](https://docs.qmk.fm/features/unicode)

|Key|Aliases|Description|
|---|---|---|
|`UC(c)`||Send Unicode code point `c`, up to `0x7FFF`|
|`UM(i)`||Send Unicode code point at index `i` in `unicode_map`|
|`UP(i, j)`||Send Unicode code point at index `i`, or `j` if Shift/Caps is on|
|`QK_UNICODE_MODE_NEXT`|`UC_NEXT`|Cycle through selected input modes|
|`QK_UNICODE_MODE_PREVIOUS`|`UC_PREV`|Cycle through selected input modes in reverse|
|`QK_UNICODE_MODE_MACOS`|`UC_MAC`|Switch to macOS input|
|`QK_UNICODE_MODE_LINUX`|`UC_LINX`|Switch to Linux input|
|`QK_UNICODE_MODE_WINDOWS`|`UC_WIN`|Switch to Windows input|
|`QK_UNICODE_MODE_BSD`|`UC_BSD`|Switch to BSD input (not implemented)|
|`QK_UNICODE_MODE_WINCOMPOSE`|`UC_WINC`|Switch to Windows input using WinCompose|
|`QK_UNICODE_MODE_EMACS`|`UC_EMAC`|Switch to emacs (`C-x-8 RET`)|

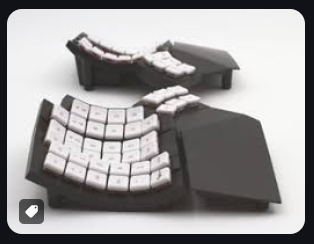
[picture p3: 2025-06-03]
obsidian/Keyboards/_images/kb_glove_80.png

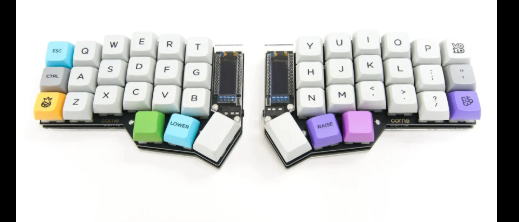
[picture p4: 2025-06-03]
obsidian/Keyboards/_images/kb_corne.png

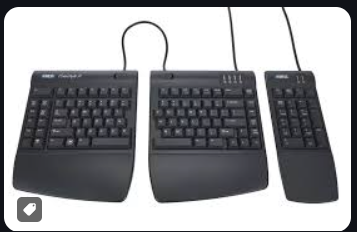
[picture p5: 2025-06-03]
obsidian/Keyboards/_images/kb_kinesis_freestyle_2.png

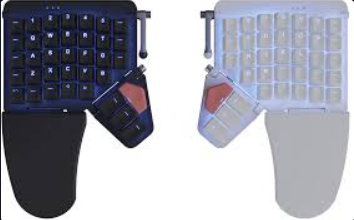
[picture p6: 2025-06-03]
obsidian/Keyboards/_images/kb_zsa_moonlander.png

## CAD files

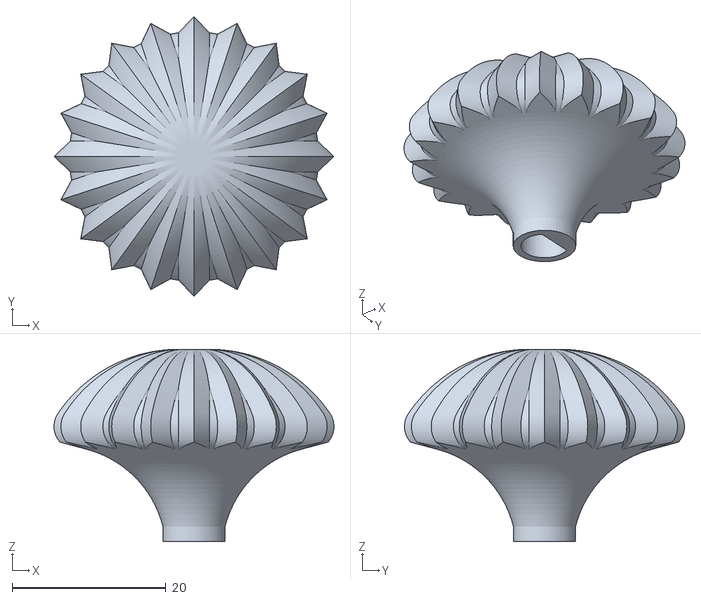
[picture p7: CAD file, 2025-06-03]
3d_files/encodercaps/Encoder Caps v13.stl
36.4 x 36.4 x 25.0

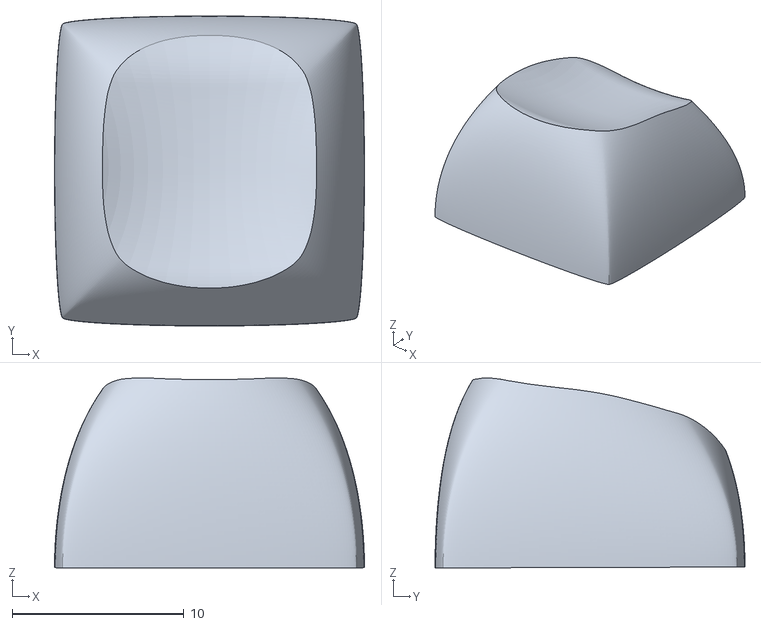
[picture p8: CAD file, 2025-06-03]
3d_files/keycaps/R4-keycap-MX-DES-stem-0.055.stl
18.1 x 18.1 x 11.1

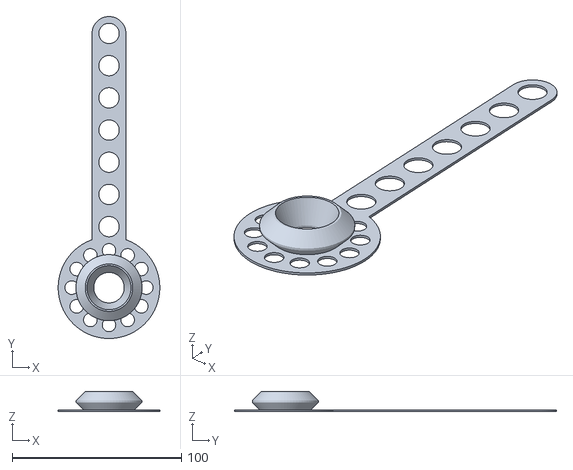
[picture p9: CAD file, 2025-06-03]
3d_files/V1/Split Keyboard Wirstrest Base.stl
60.0 x 190.0 x 12.0

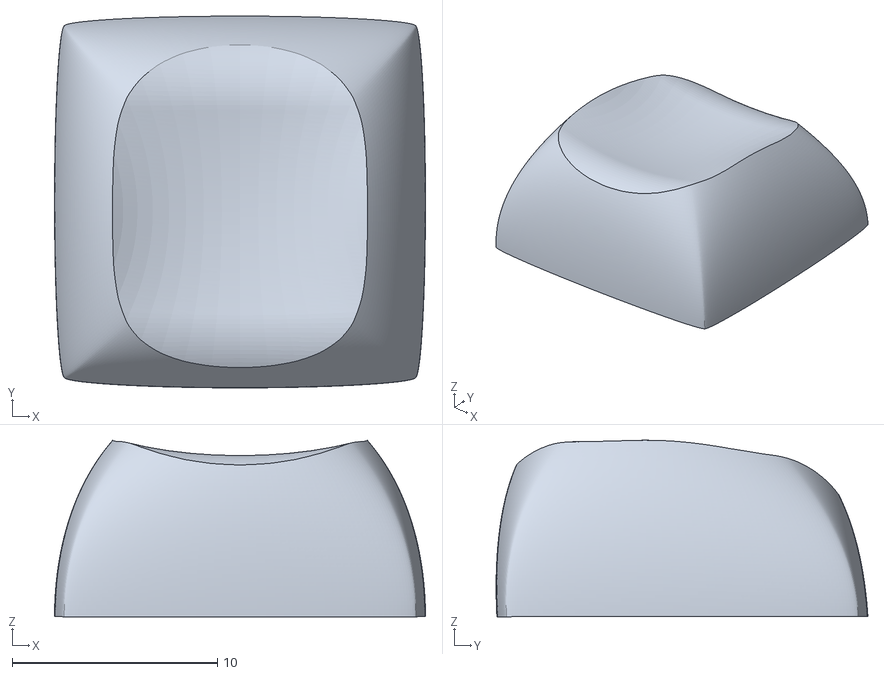
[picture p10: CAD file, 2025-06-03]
3d_files/keycaps/R3-homerow-keycap-MX-DES-stem-0.055.stl
18.1 x 18.1 x 8.60

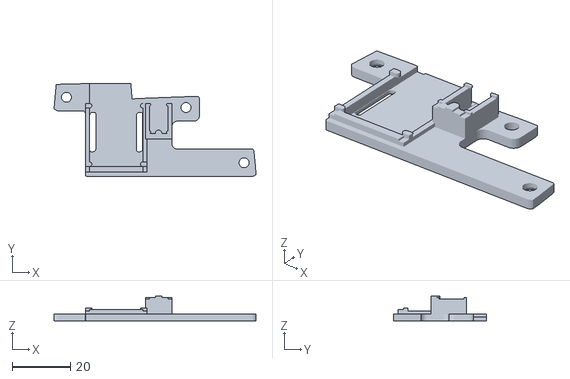
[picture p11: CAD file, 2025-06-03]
3d_files/V1/cosmotyl-holderleft.stl
69.1 x 31.7 x 8.50

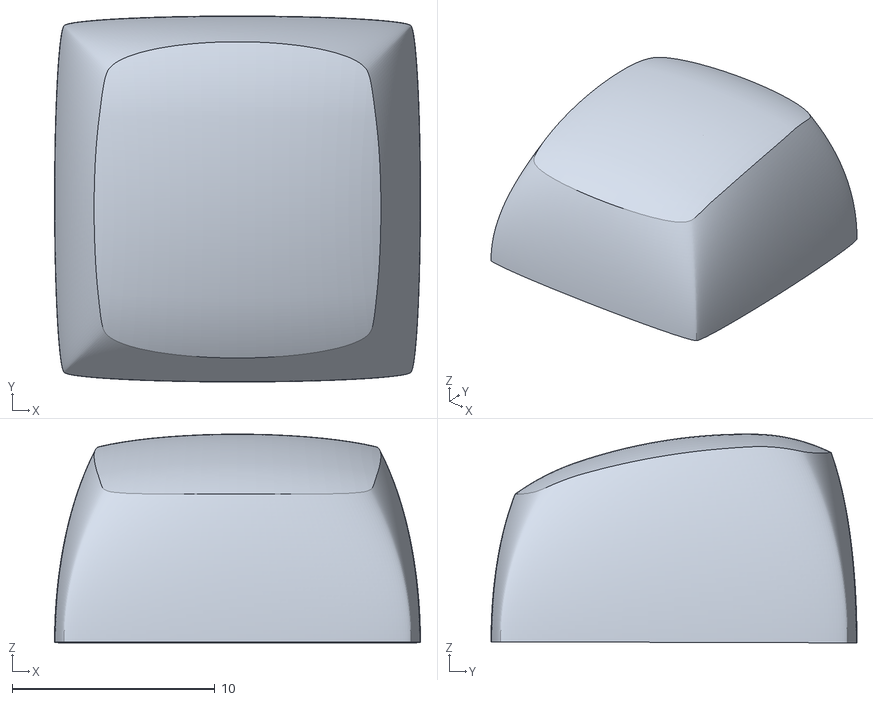
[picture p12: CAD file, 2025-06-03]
3d_files/keycaps/Thumbkeys-MX-DES-stem-0.055.stl
18.1 x 18.1 x 10.3

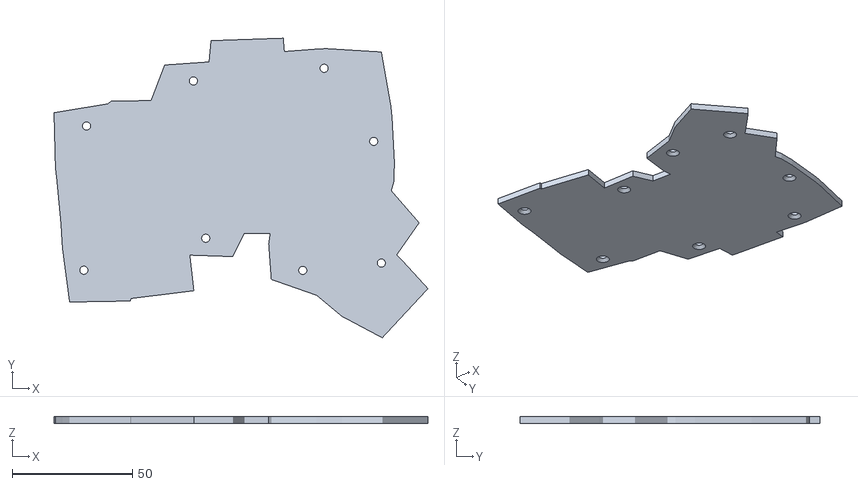
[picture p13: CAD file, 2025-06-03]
3d_files/V1/cosmotyl-plateleft.stl
155.4 x 124.4 x 3.00

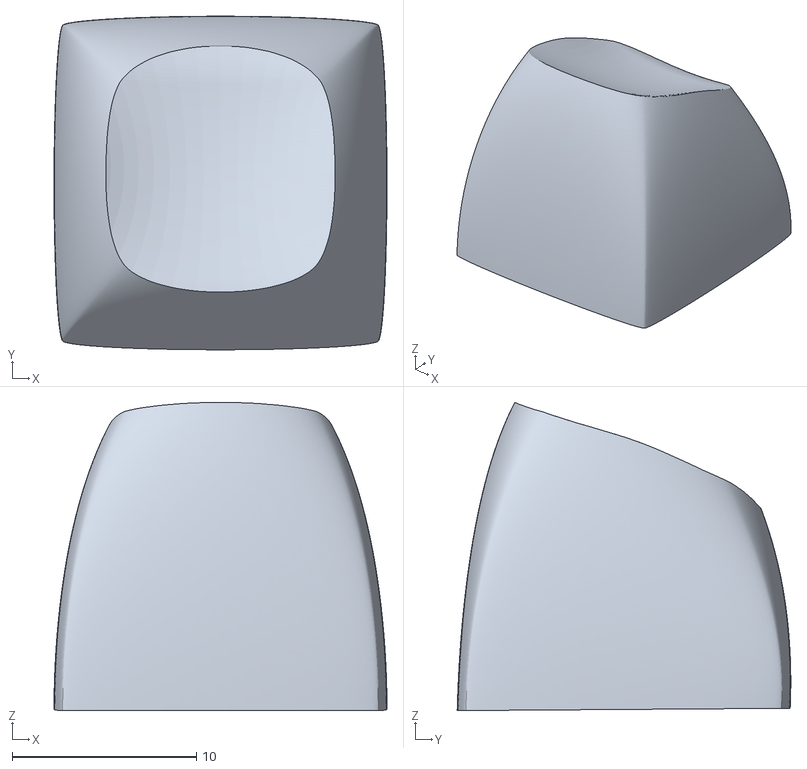
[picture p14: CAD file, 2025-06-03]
3d_files/keycaps/R1-keycap-MX-DES-stem-0.055.stl
18.1 x 18.1 x 16.7

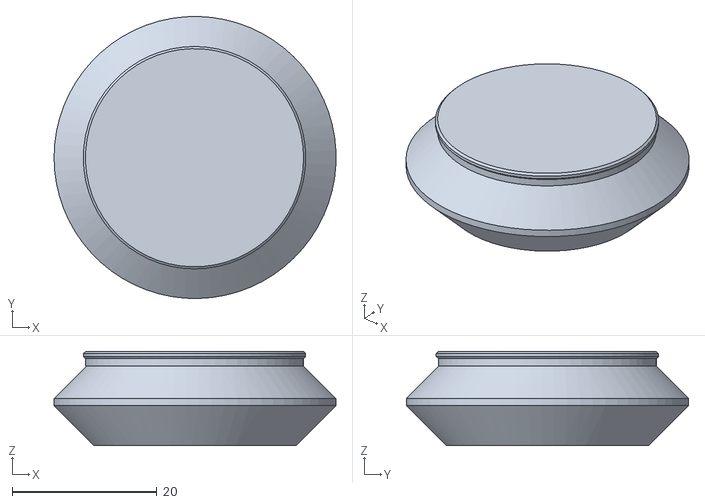
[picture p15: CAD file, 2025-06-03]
3d_files/V1/Split Keyboard Wristrest Con_top.stl
39.0 x 39.0 x 13.0

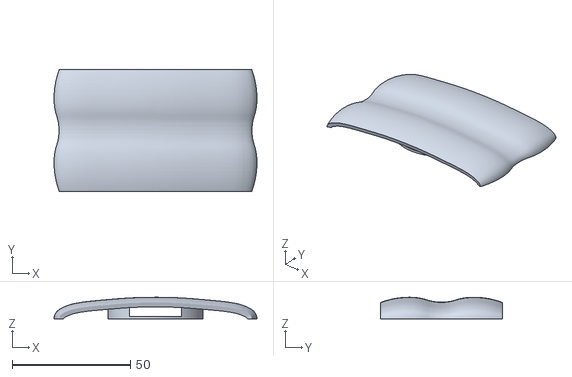
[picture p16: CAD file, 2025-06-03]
3d_files/V1/Split Keyboard Wirstrest.stl
85.7 x 51.4 x 9.09

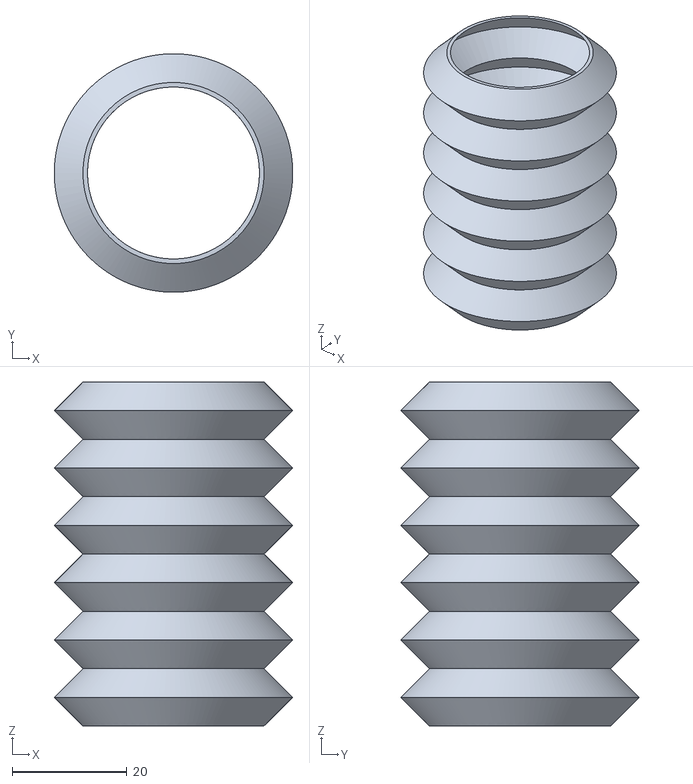
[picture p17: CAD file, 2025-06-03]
3d_files/V1/Split Keyboard Wirstrest Con.stl
41.6 x 41.6 x 60.0

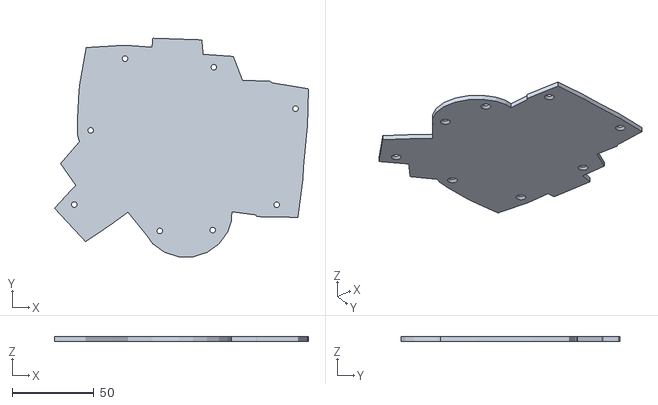
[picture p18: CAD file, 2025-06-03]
3d_files/V1/cosmotyl-plateright.stl
155.4 x 133.7 x 3.00

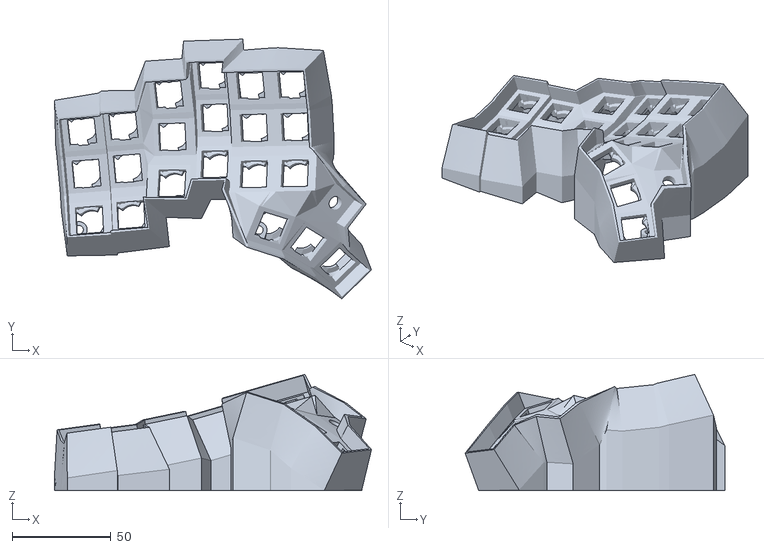
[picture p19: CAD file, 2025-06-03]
3d_files/V1/cosmotyl-caseleft.stl
160.3 x 131.3 x 58.7

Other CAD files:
3d_files/keycaps/R3-homerow-with-bump-keycap-MX-DES-stem-0.055.stl
3d_files/V1/cosmotyl-holderright.stl
3d_files/keycaps/R2-keycap-MX-DES-stem-0.055.stl

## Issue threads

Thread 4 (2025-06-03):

Encoders too hard to rotate

PDanner-EI, 2025-06-03:
If the keyboard feet are getting slippy, rotating the encoders moves the keyboards. Also they require large radius caps to effortlessly rotate.

Solution:
Get softer encoders of **similar design**.

WARNING:
The cosmos keyboard generator and qmk currently only support EC11 encoders. Look into if and how to exchange them with other series. Dimensions not a big issue since it's held in place with a nut and handwired. But not sure how widely the signal output changes between series/types.

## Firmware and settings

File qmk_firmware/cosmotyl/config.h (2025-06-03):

#pragma once

#define EE_HANDS // Store which side I am in EEPROM

/* Encoders */
//#define ENCODER_A_PINS  { GPIO10}
//#define ENCODER_B_PINS  { GPIO9}
//#define ENCODER_RESOLUTION 4

//#define ENCODER_MAP_KEY_DELAY 10

/* Trackball */
/*#define SPI_DRIVER SPID0
#define SPI_SCK_PIN GPIO14
#define SPI_MISO_PIN GPIO12
#define SPI_MOSI_PIN GPIO15
#define POINTING_DEVICE_CS_PIN GPIO13
#define ROTATIONAL_TRANSFORM_ANGLE -30 // Optional: Rotates the trackball
#define POINTING_DEVICE_INVERT_X // Optional: Inverts trackball X*/

/* Reset */
#define RP2040_BOOTLOADER_DOUBLE_TAP_RESET // Activates the double-tap behavior
#define RP2040_BOOTLOADER_DOUBLE_TAP_RESET_TIMEOUT 200U // Timeout window in ms in which the double tap can occur.
// This LED blinks when entering bootloader

#define BOOTMAGIC_ROW 0
#define BOOTMAGIC_COLUMN 0

#define BOOTMAGIC_ROW_RIGHT 4
#define BOOTMAGIC_COLUMN_RIGHT 0

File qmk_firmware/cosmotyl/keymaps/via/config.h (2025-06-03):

#define TRI_LAYER_LOWER_LAYER 2
#define TRI_LAYER_UPPER_LAYER 3
#define TRI_LAYER_ADJUST_LAYER 4

#define DYNAMIC_KEYMAP_LAYER_COUNT 5

#define PERMISSIVE_HOLD

#define TAPPING_TOGGLE 2

#define ENABLE_RGB_MATRIX_CYCLE_LEFT_RIGHT
#define ENABLE_RGB_MATRIX_CYCLE_UP_DOWN
#define RGB_MATRIX_DEFAULT_MODE RGB_MATRIX_CYCLE_LEFT_RIGHT
#define RGB_MATRIX_MAXIMUM_BRIGHTNESS 50

#define SPI_DRIVER SPID1
#define SPI_SCK_PIN GP14
#define SPI_MISO_PIN GP12
#define SPI_MOSI_PIN GP15
#define POINTING_DEVICE_CS_PIN GP13

// The trackball is quite sensitive to how
// large the liftoff distance should be.
#define PMW33XX_LIFTOFF_DISTANCE 0x02
// Sets the mouse resolution, up to 16000.
#define PMW33XX_CPI 600
// The directions where messed up, this fixes it.
//#define POINTING_DEVICE_ROTATION_270 
//#define POINTING_DEVICE_INVERT_X
#define POINTING_DEVICE_INVERT_Y

#define SPLIT_POINTING_ENABLE
// The trackball is on the right
#define POINTING_DEVICE_RIGHT
